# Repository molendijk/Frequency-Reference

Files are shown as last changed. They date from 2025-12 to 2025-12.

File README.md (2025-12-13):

  # 10MHz Frequency Reference Distributor and 25MHz generator and distributor.

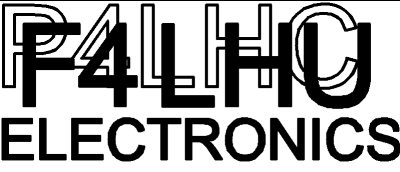
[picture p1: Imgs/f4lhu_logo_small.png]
F4LHU Logo
  
  
  ## Purpose
  
  This hardware project is intended for people posessing a 10MHz sinusoidal reference oscillator (GPS DO / Rubidium Source) 
  but require a 25MHz reference for use with an SDR (Adalm-Pluto), ADF4351 (Evaluation board) or a 
  LNB (modified Bulls-Eye).
  
  https://www.analog.com/en/resources/evaluation-hardware-and-software/evaluation-boards-kits/adalm-pluto.html
  https://github.com/molendijk/QO100_LO_ADF4351_Loader
  https://3b8mars.org/wp-content/uploads/2023/10/Bulleye-LNB-modification-for-external-clocking-updated-Oct2023.pdf

  ## Implementation

  The circuit first converts the incoming sine-wave to a square-wave. A potentiometer allows to set the square-wave
  duty factor to 50%. This square-wave is then presented to 3 external outputs of which 1 is DC coupled. A 4th internal
  copy is then available internally to be connected to the input of an external 50MHz band-pass filter.
  The 50MHz sinusoidal output of this filter is then connected to the 50MHz input, that is once again transformed to a 
  square-wave and finally divided by 2 to generate 25MHz that is presented to 4 outputs of which 2 are DC coupled.
  
  The circuit also has an interface J6 for the required power supplies (+15V, +5V) for the FE-5650 Rb frequency standard.
  As the FE-5650 module uses a 9 pin Cannon D connector, a special flat-cable with on one side the DB9 F and on the other
  side a 2 x 7 header is needed. The pin correspondances are marked in a table on page 2 of the schematic.
  Note that pin 1 of either connector are aligned (connected).
  
  ## Mounting sequence and Commissioning
  
  ### Preparations
  1. Solder SMD parts on F-side and B-side **EXCEPT: power jumpers R10, R14, R22 and Edge-mount coax connectors**
  2. Solder through-hole parts: potentiometer R15 and U6 regulator, LEDs D1 and D2 (Square pin is the cathode -> short leg).
  ### Power-supply
  3. Connect VBUS to a 16V power-supply and while measuring (with a DVM) the voltage between TP_GND and TP_15V
     trim potentiometer R15 to obtain 15V.
  4. Solder through-hole parts: potentiometers R12, R17 and regulators U2, U3.
  5. Trim potentiometer R17 while measuring TP_P5V to get 5V
  6. Trim potentiometer R12 while measuring TP_P3V3 to get 3.3V
  7. Solder power jumpers: R10, R14 (+5V and +3.3V) and measure the current going into VBUS (IBUS) to be ~30mA. 
  LED D2 should be lit.
  ### 10MHz distributor
  8. Solder Edge-mount SMA coax J1, J2, J3, J4, transistor Q1 and potentiometer R5.
  9. Inject 10MHz ~1.3Vpp in port 10MHz in (J4).
  9. With a DSO (Inputs high-Z) measure the signals at J1, J2 -> ~3.5Vpp AC and J3 -> ~3.5V DC (0 thru +3.5V)
  10. Trim R5 for 50% duty-factor (J1, J2 and J3) Note: V-bias at node C1, R6, R3 will be ~ +1.55V  
  ### 50MHz output
  11. Solder Edge-mount SMA coax J13, through-hole SMA coax: J5, J7, power jumper R22 (+15V, 50MHz gain stage), 
  transistor Q2 and potentiometer R23. 
  12. Connect a previously prepared BPF50 from port BPF50 in (J7) to BPF50 out (J5)
  13. With a DSO (Inputs high-Z) measure the signals on port MHz50 out (J13). -> 50MHz signal ~3.5Vpp AC
  14. Trim R23 for 50% duty-factor 
  ### 25MHz distributor
  15. Solder Edge-mount SMA coax : J9, J10, J11 and J12.
  16. With a DSO (Inputs high-Z) measure the signals on ports J9, J10: 25 MHz DC -> ~3.5V DC (0 thru +3.5V)
  17. With a DSO (Inputs high-Z) measure the signals on ports J11, J12: 25 MHz AC -> ~3.5V AC (50% duty-factor)
 
 Notes: 
  - At the level 17 test configuration IBUS ~0.2A at VBUS +16V
  - Regulator U3 will become hot (70°C) without any heatsink. This may be a good moment to add the heatsink.
  
  18. Connect a flat-cable to J6 and **before connecting the correct Rb reference (FE-5650)**, 
  measure the supply voltages on the DB9 connector.
  
| Pin | Function |
| --- | --- |
|  1  | +15V |
|  2  | Gnd +15V |
|  4  | +5V |
|  5  | Gnd +5V  |
	
  19. Power-down, connect the DB9 side of the flat-cable to the Rb reference, connect the Rb reference 10MHz output
  to J4 the 10MHz input.
  20. Power-up, check supplies, verify and if needed correct the 10MHz 50% duty-factor setting R5. 
  LED D1 should be lit once the Rb reference has reached operating temperature and is frequency locked.
  
  Notes: 
  - The FE-5650 will initially, while heating up, draw >1A from the 15V regulator.
  - The FE-5650 takes a few minutes to heat up and lock to the correct frequency.
  
  ## Trouble shooting
  - In case of no output on the 50MHz port, measure the DC voltages at the outputs of U4 (+3.4V) and U5 (+4.9V).
  If one of these is absent, verify the solder joints of either L1 or L2.
 
  ## Issues with Rev 1.0.0 built 20251031
  - The SMA Edge-mount connector footprints have a greater ground pin spacing than the "standard" Edge-mount SMA
  connectors available. Nevertheless these connectors can be soldered in place, bridging the slight gap between
  the pads and the connector Gnd pins.
  - The TO92 footprint of transistors Q1, Q2 (2N2222) has pin numbering 1,2,3 instead of 3,2,1 (collector emitter swap).
  The workaround is to mount Q1 and Q2 with the flat side opposite to that on the serigraphie.
  - C21 is too close to J6, the 2 x 7 pin header, effectively falling underneath the header plastic. By first mounting
  C21 and then letting the header stick out sufficiently the connector and capacitor can cohabitate.
  - As the 39 nF capacitors are not in the standard series these were replaced by 47 nF capacitors.

  ## Notes
  1. The series terminated DC Coupled outputs are intended to be connected to high-Z (3.3V) logic level inputs.
     The AC Coupled outputs can be terminated in 50 Ohms, typically like when connected to a clock input of an SDR.
  2. The 6th order 50MHz filter is constructed using 3 side-coupled (LC) resonating circuits that yield a good quality factor.
     More details on the construction of this filter will follow soon. 
  3. Certain devices need a sinusoidal 25MHz clock to operate correctly. In this case a simple low-pass filter can
     be used to remove much of the higher harmonics.
  4. Be sure to check permitted input signal levels on 25MHz inputs and if needed, add additional attenuation.

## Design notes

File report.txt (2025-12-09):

Info: Processing symbol 'C1:Capacitor_SMD:C_1206_3216Metric_Pad1.33x1.80mm_HandSolder'.
Info: Processing symbol 'R5:Resistor_SMD:R_1206_3216Metric_Pad1.30x1.75mm_HandSolder'.
Info: Processing symbol 'C21:Capacitor_SMD:C_1206_3216Metric_Pad1.33x1.80mm_HandSolder'.
Info: Processing symbol 'C2:Capacitor_SMD:C_1206_3216Metric_Pad1.33x1.80mm_HandSolder'.
Info: Processing symbol 'J13:Connector_Coaxial:SMA_Amphenol_132289_EdgeMount'.
Info: Processing symbol 'J2:Connector_Coaxial:SMA_Amphenol_132289_EdgeMount'.
Info: Processing symbol 'C3:Capacitor_SMD:C_1206_3216Metric_Pad1.33x1.80mm_HandSolder'.
Info: Processing symbol 'Q1:Package_TO_SOT_THT:TO-92_Inline'.
Info: Processing symbol 'C9:Capacitor_SMD:C_1206_3216Metric_Pad1.33x1.80mm_HandSolder'.
Info: Processing symbol 'C4:Capacitor_SMD:C_1206_3216Metric_Pad1.33x1.80mm_HandSolder'.
Info: Processing symbol 'C24:Capacitor_SMD:C_1206_3216Metric_Pad1.33x1.80mm_HandSolder'.
Info: Processing symbol 'R2:Resistor_SMD:R_2512_6332Metric_Pad1.40x3.35mm_HandSolder'.
Info: Processing symbol 'J3:Connector_Coaxial:SMA_Amphenol_132289_EdgeMount'.
Info: Processing symbol 'R7:Resistor_SMD:R_1206_3216Metric_Pad1.30x1.75mm_HandSolder'.
Info: Processing symbol 'C5:Capacitor_SMD:C_1206_3216Metric_Pad1.33x1.80mm_HandSolder'.
Info: Processing symbol 'C16:Capacitor_SMD:C_1206_3216Metric_Pad1.33x1.80mm_HandSolder'.
Info: Processing symbol 'C19:Capacitor_SMD:C_1206_3216Metric_Pad1.33x1.80mm_HandSolder'.
Info: Processing symbol 'C13:Capacitor_SMD:C_1206_3216Metric_Pad1.33x1.80mm_HandSolder'.
Info: Processing symbol 'C6:Capacitor_SMD:C_1206_3216Metric_Pad1.33x1.80mm_HandSolder'.
Info: Processing symbol 'L1:Library:Minicircuits_GU1604'.
Info: Processing symbol 'R6:Resistor_SMD:R_1206_3216Metric_Pad1.30x1.75mm_HandSolder'.
Info: Processing symbol 'J10:Connector_Coaxial:SMA_Amphenol_132289_EdgeMount'.
Info: Processing symbol 'C22:Capacitor_SMD:C_1206_3216Metric_Pad1.33x1.80mm_HandSolder'.
Info: Processing symbol 'C10:Capacitor_SMD:C_1206_3216Metric_Pad1.33x1.80mm_HandSolder'.
Info: Processing symbol 'J9:Connector_Coaxial:SMA_Amphenol_132289_EdgeMount'.
Info: Processing symbol 'R8:Resistor_SMD:R_1206_3216Metric_Pad1.30x1.75mm_HandSolder'.
Info: Processing symbol 'J8:Connector_PinHeader_2.54mm:PinHeader_2x07_P2.54mm_Vertical'.
Info: Processing symbol 'J6:Connector_Coaxial:SMA_Amphenol_132289_EdgeMount'.
Info: Processing symbol 'C25:Capacitor_SMD:C_1206_3216Metric_Pad1.33x1.80mm_HandSolder'.
Info: Processing symbol 'J11:Connector_Coaxial:SMA_Amphenol_132289_EdgeMount'.
Info: Processing symbol 'C17:Capacitor_SMD:C_1206_3216Metric_Pad1.33x1.80mm_HandSolder'.
Info: Processing symbol 'C7:Capacitor_SMD:C_1206_3216Metric_Pad1.33x1.80mm_HandSolder'.
Info: Processing symbol 'C14:Capacitor_SMD:C_1206_3216Metric_Pad1.33x1.80mm_HandSolder'.
Info: Processing symbol 'R3:Resistor_SMD:R_1206_3216Metric_Pad1.30x1.75mm_HandSolder'.
Info: Processing symbol 'C20:Capacitor_SMD:C_1206_3216Metric_Pad1.33x1.80mm_HandSolder'.
Info: Processing symbol 'J7:Connector_Coaxial:SMA_Amphenol_132289_EdgeMount'.
Info: Processing symbol 'C11:Capacitor_SMD:C_1206_3216Metric_Pad1.33x1.80mm_HandSolder'.
Info: Processing symbol 'R1:Resistor_SMD:R_2512_6332Metric_Pad1.40x3.35mm_HandSolder'.
Info: Processing symbol 'J12:Connector_Coaxial:SMA_Amphenol_132289_EdgeMount'.
Info: Processing symbol 'C23:Capacitor_SMD:C_1206_3216Metric_Pad1.33x1.80mm_HandSolder'.
Info: Processing symbol 'L2:Library:Minicircuits_GU1604'.
Info: Processing symbol 'J4:Connector_Coaxial:SMA_Amphenol_132289_EdgeMount'.
Info: Processing symbol 'R4:Resistor_SMD:R_1206_3216Metric_Pad1.30x1.75mm_HandSolder'.
Info: Processing symbol 'C8:Capacitor_SMD:C_1206_3216Metric_Pad1.33x1.80mm_HandSolder'.
Info: Processing symbol 'Q2:Package_TO_SOT_THT:TO-92_Inline'.
Info: Processing symbol 'C18:Capacitor_SMD:C_1206_3216Metric_Pad1.33x1.80mm_HandSolder'.
Info: Processing symbol 'C15:Capacitor_SMD:C_1206_3216Metric_Pad1.33x1.80mm_HandSolder'.
Info: Processing symbol 'J5:Connector_BarrelJack:BarrelJack_Horizontal'.
Info: Processing symbol 'J1:Connector_Coaxial:SMA_Amphenol_132289_EdgeMount'.
Info: Processing symbol 'C12:Capacitor_SMD:C_1206_3216Metric_Pad1.33x1.80mm_HandSolder'.
Info: Processing symbol 'R9:Resistor_SMD:R_1206_3216Metric_Pad1.30x1.75mm_HandSolder'.
Info: Processing symbol 'R10:Resistor_SMD:R_1206_3216Metric_Pad1.30x1.75mm_HandSolder'.
Info: Processing symbol 'R11:Potentiometer_THT:Potentiometer_Bourns_3299W_Vertical'.
Info: Processing symbol 'R12:Resistor_SMD:R_1206_3216Metric_Pad1.30x1.75mm_HandSolder'.
Info: Processing symbol 'R13:Potentiometer_THT:Potentiometer_Bourns_3299W_Vertical'.
Info: Processing symbol 'R14:Resistor_SMD:R_1206_3216Metric_Pad1.30x1.75mm_HandSolder'.
Info: Processing symbol 'R15:Potentiometer_THT:Potentiometer_Bourns_3299W_Vertical'.
Info: Processing symbol 'R16:Resistor_SMD:R_1206_3216Metric_Pad1.30x1.75mm_HandSolder'.
Info: Processing symbol 'R17:Resistor_SMD:R_1206_3216Metric_Pad1.30x1.75mm_HandSolder'.
Info: Processing symbol 'R18:Resistor_SMD:R_1206_3216Metric_Pad1.30x1.75mm_HandSolder'.
Info: Processing symbol 'R19:Resistor_SMD:R_1206_3216Metric_Pad1.30x1.75mm_HandSolder'.
Info: Processing symbol 'R20:Resistor_SMD:R_1206_3216Metric_Pad1.30x1.75mm_HandSolder'.
Info: Processing symbol 'R21:Potentiometer_THT:Potentiometer_Bourns_3299W_Vertical'.
Info: Processing symbol 'R22:Resistor_SMD:R_1206_3216Metric_Pad1.30x1.75mm_HandSolder'.
Info: Processing symbol 'R23:Resistor_SMD:R_1206_3216Metric_Pad1.30x1.75mm_HandSolder'.
Info: Processing symbol 'R24:Resistor_SMD:R_1206_3216Metric_Pad1.30x1.75mm_HandSolder'.
Info: Processing symbol 'R25:Resistor_SMD:R_1206_3216Metric_Pad1.30x1.75mm_HandSolder'.
Info: Processing symbol 'R26:Resistor_SMD:R_1206_3216Metric_Pad1.30x1.75mm_HandSolder'.
Info: Processing symbol 'R27:Resistor_SMD:R_1206_3216Metric_Pad1.30x1.75mm_HandSolder'.
Info: Total warnings: 9, errors: 0.
Info: Processing symbol 'R28:Resistor_SMD:R_1206_3216Metric_Pad1.30x1.75mm_HandSolder'.
Info: Processing symbol 'R29:Potentiometer_THT:Potentiometer_Bourns_3299W_Vertical'.
Info: Processing symbol 'R30:Resistor_SMD:R_1206_3216Metric_Pad1.30x1.75mm_HandSolder'.
Info: Processing symbol 'R31:Resistor_SMD:R_1206_3216Metric_Pad1.30x1.75mm_HandSolder'.
Info: Processing symbol 'R32:Resistor_SMD:R_1206_3216Metric_Pad1.30x1.75mm_HandSolder'.
Info: Processing symbol 'TP1:TestPoint:TestPoint_Plated_Hole_D2.0mm'.
Info: Processing symbol 'TP2:TestPoint:TestPoint_Plated_Hole_D2.0mm'.
Info: Processing symbol 'TP3:TestPoint:TestPoint_Plated_Hole_D2.0mm'.
Info: Processing symbol 'TP4:TestPoint:TestPoint_Plated_Hole_D2.0mm'.
Info: Processing symbol 'TP5:TestPoint:TestPoint_Plated_Hole_D2.0mm'.
Info: Processing symbol 'TP6:TestPoint:TestPoint_Plated_Hole_D2.0mm'.
Info: Processing symbol 'TP7:TestPoint:TestPoint_Plated_Hole_D2.0mm'.
Info: Processing symbol 'TP8:TestPoint:TestPoint_Plated_Hole_D2.0mm'.
Info: Processing symbol 'U1:Library:WW107'.
Info: Processing symbol 'U2:Library:WW107'.
Info: Processing symbol 'U3:Package_SO:SSOP-8_2.95x2.8mm_P0.65mm'.
Info: Processing symbol 'U4:Package_TO_SOT_SMD:TO-263-3_TabPin2'.
Info: Processing symbol 'U5:Package_SO:SOIC-8_5.3x6.2mm_P1.27mm'.
Info: Processing symbol 'U6:Package_SO:SOIC-8_5.3x6.2mm_P1.27mm'.
Info: Processing symbol 'U7:Package_TO_SOT_SMD:TO-263-3_TabPin2'.
Info: Processing symbol 'U8:Package_TO_SOT_SMD:TO-263-3_TabPin2'.
Info: Processing symbol 'U9:Package_SO:SOIC-8_5.3x6.2mm_P1.27mm'.
Updated C8 sheetfile to 'ClockDistri.kicad_sch'.
Updated C8 footprint filters to 'CP_*'.
Connected C8 pin 2 to GND.
Add net VBUS.
Connected C8 pin 1 to VBUS.
Added C9 (footprint 'Capacitor_SMD:C_1206_3216Metric_Pad1.33x1.80mm_HandSolder').
Changed REF** reference designator to C9.
Changed C9 value from C_1206_3216Metric_Pad1.33x1.80mm_HandSolder to 47uF.
Updated C9 symbol association from  to /19e25b7f-f11f-43c6-9ca8-c0c99fb9a488/27e5c7c0-e4c8-4e1d-91d9-dbcf634c3cf4.
Updated C9 fields.
Updated C9 sheetname to '/PowerSupplies/'.
Updated C9 sheetfile to 'ClockDistri.kicad_sch'.
Updated C9 footprint filters to 'CP_*'.
Connected C9 pin 2 to GND.
Add net Net-(J8-Pin_1).
Connected C9 pin 1 to Net-(J8-Pin_1).
Added C10 (footprint 'Capacitor_SMD:C_1206_3216Metric_Pad1.33x1.80mm_HandSolder').
Changed REF** reference designator to C10.
Changed C10 value from C_1206_3216Metric_Pad1.33x1.80mm_HandSolder to 47uF.
Updated C10 symbol association from  to /19e25b7f-f11f-43c6-9ca8-c0c99fb9a488/b20e4947-729c-45ab-a11c-5afa4ca6e5d3.
Updated C10 fields.
Updated C10 sheetname to '/PowerSupplies/'.
Updated C10 sheetfile to 'ClockDistri.kicad_sch'.
Updated C10 footprint filters to 'CP_*'.
Add net Net-(J8-Pin_7).
Connected C10 pin 1 to Net-(J8-Pin_7).
Connected C10 pin 2 to GND.
Added C11 (footprint 'Capacitor_SMD:C_1206_3216Metric_Pad1.33x1.80mm_HandSolder').
Changed REF** reference designator to C11.
Changed C11 value from C_1206_3216Metric_Pad1.33x1.80mm_HandSolder to 47uF.
Updated C11 symbol association from  to /19e25b7f-f11f-43c6-9ca8-c0c99fb9a488/a415be0a-ee04-4ad4-88dc-ad9cb893901c.
Updated C11 fields.
Updated C11 sheetname to '/PowerSupplies/'.
Updated C11 sheetfile to 'ClockDistri.kicad_sch'.
Updated C11 footprint filters to 'CP_*'.
Add net Net-(U8-VO).
Connected C11 pin 1 to Net-(U8-VO).
Connected C11 pin 2 to GND.
Added C12 (footprint 'Capacitor_SMD:C_1206_3216Metric_Pad1.33x1.80mm_HandSolder').
Changed REF** reference designator to C12.
Changed C12 value from C_1206_3216Metric_Pad1.33x1.80mm_HandSolder to 22uF.
Updated C12 symbol association from  to /19e25b7f-f11f-43c6-9ca8-c0c99fb9a488/99ee4937-7fed-4c68-beed-ca436922dd44.
Updated C12 fields.
Updated C12 sheetname to '/PowerSupplies/'.
Updated C12 sheetfile to 'ClockDistri.kicad_sch'.
Updated C12 footprint filters to 'CP_*'.
Add net Net-(U7-ADJ).
Connected C12 pin 1 to Net-(U7-ADJ).
Connected C12 pin 2 to GND.
Added C13 (footprint 'Capacitor_SMD:C_1206_3216Metric_Pad1.33x1.80mm_HandSolder').
Changed REF** reference designator to C13.
Changed C13 value from C_1206_3216Metric_Pad1.33x1.80mm_HandSolder to 22uF.
Updated C13 symbol association from  to /19e25b7f-f11f-43c6-9ca8-c0c99fb9a488/53d6d50d-ee43-436f-992a-71831d127ff6.
Updated C13 fields.
Updated C13 sheetname to '/PowerSupplies/'.
Updated C13 sheetfile to 'ClockDistri.kicad_sch'.
Updated C13 footprint filters to 'CP_*'.
Add net Net-(U8-ADJ).
Connected C13 pin 1 to Net-(U8-ADJ).
Connected C13 pin 2 to GND.
Added C14 (footprint 'Capacitor_SMD:C_1206_3216Metric_Pad1.33x1.80mm_HandSolder').
Changed REF** reference designator to C14.
Changed C14 value from C_1206_3216Metric_Pad1.33x1.80mm_HandSolder to 22uF.
Updated C14 symbol association from  to /19e25b7f-f11f-43c6-9ca8-c0c99fb9a488/779a9825-380a-40c6-be76-97d7fdc0159a.
Updated C14 fields.
Updated C14 sheetname to '/PowerSupplies/'.
Updated C14 sheetfile to 'ClockDistri.kicad_sch'.
Updated C14 footprint filters to 'CP_*'.
Connected C14 pin 2 to GND.
Add net Net-(U4-ADJ).
Connected C14 pin 1 to Net-(U4-ADJ).
Added C15 (footprint 'Capacitor_SMD:C_1206_3216Metric_Pad1.33x1.80mm_HandSolder').
Changed REF** reference designator to C15.
Changed C15 value from C_1206_3216Metric_Pad1.33x1.80mm_HandSolder to 100nF.
Updated C15 symbol association from  to /587d7fd0-7b34-44bf-a0ec-ae7bf4ed02c7.
Updated C15 fields.
Updated C15 sheetname to '/'.
Updated C15 sheetfile to 'Freq_Reference.kicad_sch'.
Updated C15 footprint filters to 'C_*'.
Connected C15 pin 1 to GND.
Add net Net-(Q2-B).
Connected C15 pin 2 to Net-(Q2-B).
Added C16 (footprint 'Capacitor_SMD:C_1206_3216Metric_Pad1.33x1.80mm_HandSolder').
Changed REF** reference designator to C16.
Changed C16 value from C_1206_3216Metric_Pad1.33x1.80mm_HandSolder to 39nF.
Updated C16 symbol association from  to /6c447208-1996-437b-8c30-de446bbd3cab.
Updated C16 fields.
Updated C16 sheetname to '/'.
Updated C16 sheetfile to 'Freq_Reference.kicad_sch'.
Updated C16 footprint filters to 'C_*'.
Add net Net-(C16-Pad1).
Connected C16 pin 1 to Net-(C16-Pad1).
Connected C16 pin 2 to GND.
Added C17 (footprint 'Capacitor_SMD:C_1206_3216Metric_Pad1.33x1.80mm_HandSolder').
Changed REF** reference designator to C17.
Changed C17 value from C_1206_3216Metric_Pad1.33x1.80mm_HandSolder to 1uF.
Updated C17 symbol association from  to /ebffa0a9-fa4d-4ada-a95c-21fc8a085352.
Updated C17 fields.
Updated C17 sheetname to '/'.
Updated C17 sheetfile to 'Freq_Reference.kicad_sch'.
Updated C17 footprint filters to 'C_*'.
Connected C17 pin 2 to Net-(C16-Pad1).
Connected C17 pin 1 to GND.
Added C18 (footprint 'Capacitor_SMD:C_1206_3216Metric_Pad1.33x1.80mm_HandSolder').
Changed REF** reference designator to C18.
Changed C18 value from C_1206_3216Metric_Pad1.33x1.80mm_HandSolder to 39nF.
Updated C18 symbol association from  to /673c9a1c-68e8-4ecc-9c92-ebbabf77a1cd.
Updated C18 fields.
Updated C18 sheetname to '/'.
Updated C18 sheetfile to 'Freq_Reference.kicad_sch'.
Updated C18 footprint filters to 'C_*'.
Connected C18 pin 2 to GND.
Add net Net-(Q1-E).
Connected C18 pin 1 to Net-(Q1-E).
Added C19 (footprint 'Capacitor_SMD:C_1206_3216Metric_Pad1.33x1.80mm_HandSolder').
Changed REF** reference designator to C19.
Changed C19 value from C_1206_3216Metric_Pad1.33x1.80mm_HandSolder to 39nF.
Updated C19 symbol association from  to /a4f53673-f229-4935-9d42-51c9ade87ad7.
Updated C19 fields.
Updated C19 sheetname to '/'.
Updated C19 sheetfile to 'Freq_Reference.kicad_sch'.
Updated C19 footprint filters to 'C_*'.
Connected C19 pin 2 to GND.
Add net Net-(Q2-E).
Connected C19 pin 1 to Net-(Q2-E).
Added C20 (footprint 'Capacitor_SMD:C_1206_3216Metric_Pad1.33x1.80mm_HandSolder').
Changed REF** reference designator to C20.
Changed C20 value from C_1206_3216Metric_Pad1.33x1.80mm_HandSolder to 1uF.
Updated C20 symbol association from  to /c03fc493-f095-4c8b-b1b0-a7ec03b12a23.
Updated C20 fields.
Updated C20 sheetname to '/'.
Updated C20 sheetfile to 'Freq_Reference.kicad_sch'.
Updated C20 footprint filters to 'C_*'.
Add net Net-(C20-Pad2).
Connected C20 pin 2 to Net-(C20-Pad2).
Connected C20 pin 1 to GND.
Added C21 (footprint 'Capacitor_SMD:C_1206_3216Metric_Pad1.33x1.80mm_HandSolder').
Changed REF** reference designator to C21.
Changed C21 value from C_1206_3216Metric_Pad1.33x1.80mm_HandSolder to 39nF.
Updated C21 symbol association from  to /69341308-b7ec-468b-90af-18e7545a2889.
Updated C21 fields.
Updated C21 sheetname to '/'.
Updated C21 sheetfile to 'Freq_Reference.kicad_sch'.
Updated C21 footprint filters to 'C_*'.
Connected C21 pin 2 to GND.
Connected C21 pin 1 to Net-(C20-Pad2).
Added C22 (footprint 'Capacitor_SMD:C_1206_3216Metric_Pad1.33x1.80mm_HandSolder').
Changed REF** reference designator to C22.
Changed C22 value from C_1206_3216Metric_Pad1.33x1.80mm_HandSolder to 39nF.
Updated C22 symbol association from  to /09e92692-0717-472e-b4b6-a50c8216932f.
Updated C22 fields.
Updated C22 sheetname to '/'.
Updated C22 sheetfile to 'Freq_Reference.kicad_sch'.
Updated C22 footprint filters to 'C_*'.
Connected C22 pin 1 to +3.3V.
Connected C22 pin 2 to GND.
Added C23 (footprint 'Capacitor_SMD:C_1206_3216Metric_Pad1.33x1.80mm_HandSolder').
Changed REF** reference designator to C23.
Changed C23 value from C_1206_3216Metric_Pad1.33x1.80mm_HandSolder to 39nF.
Updated C23 symbol association from  to /9c059ba8-eb20-4027-9856-53d2b9bf8cac.
Updated C23 fields.
Updated C23 sheetname to '/'.
Updated C23 sheetfile to 'Freq_Reference.kicad_sch'.
Updated C23 footprint filters to 'C_*'.
Connected C23 pin 2 to GND.
Connected C23 pin 1 to +3.3V.
Added C24 (footprint 'Capacitor_SMD:C_1206_3216Metric_Pad1.33x1.80mm_HandSolder').
Changed REF** reference designator to C24.
Changed C24 value from C_1206_3216Metric_Pad1.33x1.80mm_HandSolder to 39nF.
Updated C24 symbol association from  to /670d0a66-c874-48b3-ac8c-e8d85d931bfe.
Updated C24 fields.
Updated C24 sheetname to '/'.
Updated C24 sheetfile to 'Freq_Reference.kicad_sch'.
Updated C24 footprint filters to 'C_*'.
Connected C24 pin 2 to GND.
Connected C24 pin 1 to +3.3V.
Added C25 (footprint 'Capacitor_SMD:C_1206_3216Metric_Pad1.33x1.80mm_HandSolder').
Changed REF** reference designator to C25.
Changed C25 value from C_1206_3216Metric_Pad1.33x1.80mm_HandSolder to 39nF.
Updated C25 symbol association from  to /faf82ec7-362b-495d-863f-135f0d69d378.
Updated C25 fields.
Updated C25 sheetname to '/'.
Updated C25 sheetfile to 'Freq_Reference.kicad_sch'.
Updated C25 footprint filters to 'C_*'.
Connected C25 pin 1 to +3.3V.
Connected C25 pin 2 to GND.
Updated J1 fields.
Updated J1 sheetfile to 'Freq_Reference.kicad_sch'.
Updated J2 fields.
Updated J2 sheetfile to 'Freq_Reference.kicad_sch'.
Added J3 (footprint 'Connector_Coaxial:SMA_Amphenol_132289_EdgeMount').
Changed REF** reference designator to J3.
Changed J3 value from SMA_Amphenol_132289_EdgeMount to Conn_Coaxial_Small.
Updated J3 symbol association from  to /53538eb5-029b-4884-8540-a9824974924f.
Updated J3 fields.
Updated J3 sheetname to '/'.
Updated J3 sheetfile to 'Freq_Reference.kicad_sch'.
Updated J3 footprint filters to '*BNC* *SMA* *SMB* *SMC* *Cinch* *LEMO* *UMRF* *MCX* *U.FL*'.
Connected J3 pin 2 to GND.
Add net Net-(J3-In).
Connected J3 pin 1 to Net-(J3-In).
Connected J3 pin 2 to GND.
Connected J3 pin 2 to GND.
Connected J3 pin 2 to GND.
Updated J4 fields.
Updated J4 sheetfile to 'Freq_Reference.kicad_sch'.
Added J5 (footprint 'Connector_BarrelJack:BarrelJack_Horizontal').
Changed REF** reference designator to J5.
Changed J5 value from BarrelJack_Horizontal to Jack-DC.
Updated J5 symbol association from  to /19e25b7f-f11f-43c6-9ca8-c0c99fb9a488/a68c2d15-3dc7-422a-a2dd-c7c9dbd4d9a6.
Updated J5 fields.
Updated J5 sheetname to '/PowerSupplies/'.
Updated J5 sheetfile to 'ClockDistri.kicad_sch'.
Updated J5 footprint filters to 'BarrelJack*'.
Connected J5 pin 2 to GND.
Connected J5 pin 1 to VBUS.
Updated J6 fields.
Updated J6 sheetfile to 'Freq_Reference.kicad_sch'.
Added J7 (footprint 'Connector_Coaxial:SMA_Amphenol_132289_EdgeMount').
Changed REF** reference designator to J7.
Changed J7 value from SMA_Amphenol_132289_EdgeMount to Conn_Coaxial_Small.
Updated J7 symbol association from  to /ade44c3a-5c98-4127-9fd3-751c3f6859d4.
Updated J7 fields.
Updated J7 sheetname to '/'.
Updated J7 sheetfile to 'Freq_Reference.kicad_sch'.
Updated J7 footprint filters to '*BNC* *SMA* *SMB* *SMC* *Cinch* *LEMO* *UMRF* *MCX* *U.FL*'.
Connected J7 pin 2 to GND.
Connected J7 pin 2 to GND.
Connected J7 pin 2 to GND.
Add net Net-(J7-In).
Connected J7 pin 1 to Net-(J7-In).
Connected J7 pin 2 to GND.
Added J8 (footprint 'Connector_PinHeader_2.54mm:PinHeader_2x07_P2.54mm_Vertical').
Changed REF** reference designator to J8.
Changed J8 value from PinHeader_2x07_P2.54mm_Vertical to Conn_02x07_Odd_Even.
Updated J8 symbol association from  to /19e25b7f-f11f-43c6-9ca8-c0c99fb9a488/282b8dfc-f45e-47d8-ac74-86026d99b6d7.
Updated J8 fields.
Updated J8 sheetname to '/PowerSupplies/'.
Updated J8 sheetfile to 'ClockDistri.kicad_sch'.
Updated J8 footprint filters to 'Connector*:*_2x??_*'.
Connected J8 pin 1 to Net-(J8-Pin_1).
Add net unconnected-(J8-Pin_10-Pad10).
Connected J8 pin 10 to unconnected-(J8-Pin_10-Pad10).
Add net unconnected-(J8-Pin_8-Pad8).
Connected J8 pin 8 to unconnected-(J8-Pin_8-Pad8).
Connected J8 pin 9 to GND.
Add net unconnected-(J8-Pin_12-Pad12).
Connected J8 pin 12 to unconnected-(J8-Pin_12-Pad12).
Add net unconnected-(J8-Pin_5-Pad5).
Connected J8 pin 5 to unconnected-(J8-Pin_5-Pad5).
Add net unconnected-(J8-Pin_13-Pad13).
Connected J8 pin 13 to unconnected-(J8-Pin_13-Pad13).
Add net unconnected-(J8-Pin_4-Pad4).
Connected J8 pin 4 to unconnected-(J8-Pin_4-Pad4).
Add net unconnected-(J8-Pin_14-Pad14).
Connected J8 pin 14 to unconnected-(J8-Pin_14-Pad14).
Connected J8 pin 2 to GND.
Add net unconnected-(J8-Pin_6-Pad6).
Connected J8 pin 6 to unconnected-(J8-Pin_6-Pad6).
Add net unconnected-(J8-Pin_11-Pad11).
Connected J8 pin 11 to unconnected-(J8-Pin_11-Pad11).
Connected J8 pin 3 to GND.
Connected J8 pin 7 to Net-(J8-Pin_7).
Added J9 (footprint 'Connector_Coaxial:SMA_Amphenol_132289_EdgeMount').
Changed REF** reference designator to J9.
Changed J9 value from SMA_Amphenol_132289_EdgeMount to Conn_Coaxial_Small.
Updated J9 symbol association from  to /3e9de054-da3d-4130-ae46-7479a23cc6ca.
Updated J9 fields.
Updated J9 sheetname to '/'.
Updated J9 sheetfile to 'Freq_Reference.kicad_sch'.
Updated J9 footprint filters to '*BNC* *SMA* *SMB* *SMC* *Cinch* *LEMO* *UMRF* *MCX* *U.FL*'.
Connected J9 pin 2 to GND.
Connected J9 pin 2 to GND.
Add net Net-(J9-In).
Connected J9 pin 1 to Net-(J9-In).
Connected J9 pin 2 to GND.
Connected J9 pin 2 to GND.
Added J10 (footprint 'Connector_Coaxial:SMA_Amphenol_132289_EdgeMount').
Changed REF** reference designator to J10.
Changed J10 value from SMA_Amphenol_132289_EdgeMount to Conn_Coaxial_Small.
Updated J10 symbol association from  to /dda4fd4b-18b2-482b-b9c9-32f06f5ca0d1.
Updated J10 fields.
Updated J10 sheetfile to 'Freq_Reference.kicad_sch'.
Updated J10 footprint filters to '*BNC* *SMA* *SMB* *SMC* *Cinch* *LEMO* *UMRF* *MCX* *U.FL*'.
Connected J10 pin 2 to GND.
Connected J10 pin 2 to GND.
Connected J10 pin 2 to GND.
Connected J10 pin 2 to GND.
Add net Net-(J10-In).
Connected J10 pin 1 to Net-(J10-In).
Added J11 (footprint 'Connector_Coaxial:SMA_Amphenol_132289_EdgeMount').
Changed REF** reference designator to J11.
Changed J11 value from SMA_Amphenol_132289_EdgeMount to Conn_Coaxial_Small.
Updated J11 symbol association from  to /da186231-41d8-448f-a09b-173a8f8d9fc9.
Updated J11 fields.
Updated J11 sheetname to '/'.
Updated J11 sheetfile to 'Freq_Reference.kicad_sch'.
Updated J11 footprint filters to '*BNC* *SMA* *SMB* *SMC* *Cinch* *LEMO* *UMRF* *MCX* *U.FL*'.
Connected J11 pin 2 to GND.
Connected J11 pin 2 to GND.
Add net Net-(J11-In).
Connected J11 pin 1 to Net-(J11-In).
Connected J11 pin 2 to GND.
Connected J11 pin 2 to GND.
Added J12 (footprint 'Connector_Coaxial:SMA_Amphenol_132289_EdgeMount').
Changed REF** reference designator to J12.
Changed J12 value from SMA_Amphenol_132289_EdgeMount to Conn_Coaxial_Small.
Updated J12 symbol association from  to /d6aadbf4-0e74-419b-bbd0-b599f2c85937.
Updated J12 fields.
Updated J12 sheetname to '/'.
Updated J12 sheetfile to 'Freq_Reference.kicad_sch'.
Updated J12 footprint filters to '*BNC* *SMA* *SMB* *SMC* *Cinch* *LEMO* *UMRF* *MCX* *U.FL*'.
Connected J12 pin 2 to GND.
Connected J12 pin 2 to GND.
Connected J12 pin 2 to GND.
Connected J12 pin 2 to GND.
Add net Net-(J12-In).
Connected J12 pin 1 to Net-(J12-In).
Added J13 (footprint 'Connector_Coaxial:SMA_Amphenol_132289_EdgeMount').
Changed REF** reference designator to J13.
Changed J13 value from SMA_Amphenol_132289_EdgeMount to Conn_Coaxial_Small.
Updated J13 symbol association from  to /c807c0ab-1d16-45ae-8be6-4f6555b1990c.
Updated J13 fields.
Updated J13 sheetname to '/'.
Updated J13 sheetfile to 'Freq_Reference.kicad_sch'.
Updated J13 footprint filters to '*BNC* *SMA* *SMB* *SMC* *Cinch* *LEMO* *UMRF* *MCX* *U.FL*'.
Connected J13 pin 2 to GND.
Connected J13 pin 2 to GND.
Connected J13 pin 2 to GND.
Connected J13 pin 1 to Net-(J13-In).
Connected J13 pin 2 to GND.
Added L1 (footprint 'Library:Minicircuits_GU1604').
Changed L** reference designator to L1.
Changed L1 value from GU1604 to TCCH-80+.
Updated L1 symbol association from  to /0653adb7-e871-48e0-ab44-da0109c4a5e6.
Updated L1 fields.
Updated L1 sheetname to '/'.
Updated L1 sheetfile to 'Freq_Reference.kicad_sch'.
Updated L1 footprint filters to 'Choke_* *Coil* Inductor_* L_*'.
Connected L1 pin 1 to Net-(C2-Pad1).
Connected L1 pin 3 to Net-(C16-Pad1).
Changed L2 footprint from 'Inductor_THT:L_Axial_L14.0mm_D4.5mm_P15.24mm_Horizontal_Fastron_LACC' to 'Library:Minicircuits_GU1604'.
Changed L2 value from 10uH to TCCH-80+.
Updated L2 fields.
Updated L2 sheetfile to 'Freq_Reference.kicad_sch'.
Connected L2 pin 3 to Net-(C20-Pad2).
Disconnected L2 pin 2.
Reconnected L2 pin 1 from Net-(L2-Pad1) to Net-(C3-Pad1).
Added Q1 (footprint 'Package_TO_SOT_THT:TO-92_Inline').
Changed REF** reference designator to Q1.
Changed Q1 value from TO-92_Inline to 2N2222.
Updated Q1 symbol association from  to /87cd8ec4-d0ee-4e28-a457-ae871a82ea1e.
Updated Q1 fields.
Updated Q1 sheetname to '/'.
Updated Q1 sheetfile to 'Freq_Reference.kicad_sch'.
Updated Q1 footprint filters to 'TO?92*'.
Connected Q1 pin 2 to Net-(Q1-B).
Connected Q1 pin 1 to Net-(Q1-E).
Connected Q1 pin 3 to +5V.
Added Q2 (footprint 'Package_TO_SOT_THT:TO-92_Inline').
Changed REF** reference designator to Q2.
Changed Q2 value from TO-92_Inline to 2N2222.
Updated Q2 symbol association from  to /b7d8b4d7-46a5-48fc-8264-01012edfd1ce.
Updated Q2 fields.
Updated Q2 sheetname to '/'.
Updated Q2 sheetfile to 'Freq_Reference.kicad_sch'.
Updated Q2 footprint filters to 'TO?92*'.
Connected Q2 pin 1 to Net-(Q2-E).
Connected Q2 pin 2 to Net-(Q2-B).
Connected Q2 pin 3 to +5V.
Changed R1 footprint from 'Resistor_THT:R_Axial_DIN0207_L6.3mm_D2.5mm_P10.16mm_Horizontal' to 'Resistor_SMD:R_2512_6332Metric_Pad1.40x3.35mm_HandSolder'.
Changed R1 value from 115 to 300.
Updated R1 fields.
Updated R1 sheetfile to 'Freq_Reference.kicad_sch'.
Reconnected R1 pin 2 from Net-(L1-Pad1) to Net-(C16-Pad1).
Reconnected R1 pin 1 from +9V to +15V.
Changed R2 footprint from 'Resistor_THT:R_Axial_DIN0207_L6.3mm_D2.5mm_P10.16mm_Horizontal' to 'Resistor_SMD:R_2512_6332Metric_Pad1.40x3.35mm_HandSolder'.
Changed R2 value from 75 to 160.
Updated R2 fields.
Updated R2 sheetfile to 'Freq_Reference.kicad_sch'.
Reconnected R2 pin 1 from +9V to +15V.
Reconnected R2 pin 2 from Net-(L2-Pad1) to Net-(C20-Pad2).
Changed R3 footprint from 'Resistor_THT:R_Axial_DIN0207_L6.3mm_D2.5mm_P10.16mm_Horizontal' to 'Resistor_SMD:R_1206_3216Metric_Pad1.30x1.75mm_HandSolder'.
Changed R3 value from 2k4 to 100.
Updated R3 fields.
Updated R3 sheetfile to 'Freq_Reference.kicad_sch'.
Reconnected R3 pin 1 from +5V to Net-(Q1-E).
Updated J10 sheetname to '/'.
Changed R4 footprint from 'Resistor_THT:R_Axial_DIN0207_L6.3mm_D2.5mm_P10.16mm_Horizontal' to 'Resistor_SMD:R_1206_3216Metric_Pad1.30x1.75mm_HandSolder'.
Changed R4 value from 2k4 to 100.
Updated R4 fields.
Updated R4 sheetfile to 'Freq_Reference.kicad_sch'.
Changed R5 footprint from 'Resistor_THT:R_Axial_DIN0207_L6.3mm_D2.5mm_P10.16mm_Horizontal' to 'Resistor_SMD:R_1206_3216Metric_Pad1.30x1.75mm_HandSolder'.
Updated R5 fields.
Updated R5 sheetfile to 'Freq_Reference.kicad_sch'.
Changed R6 footprint from 'Resistor_THT:R_Axial_DIN0207_L6.3mm_D2.5mm_P10.16mm_Horizontal' to 'Resistor_SMD:R_1206_3216Metric_Pad1.30x1.75mm_HandSolder'.
Updated R6 fields.
Updated R6 sheetfile to 'Freq_Reference.kicad_sch'.
Add net Net-(R6-Pad2).
Reconnected R6 pin 2 from Net-(J4-In) to Net-(R6-Pad2).
Changed R7 footprint from 'Resistor_THT:R_Axial_DIN0207_L6.3mm_D2.5mm_P10.16mm_Horizontal' to 'Resistor_SMD:R_1206_3216Metric_Pad1.30x1.75mm_HandSolder'.
Updated R7 fields.
Updated R7 sheetfile to 'Freq_Reference.kicad_sch'.
Add net Net-(R7-Pad2).
Reconnected R7 pin 2 from Net-(J5-In) to Net-(R7-Pad2).
Changed R8 footprint from 'Resistor_THT:R_Axial_DIN0207_L6.3mm_D2.5mm_P10.16mm_Horizontal' to 'Resistor_SMD:R_1206_3216Metric_Pad1.30x1.75mm_HandSolder'.
Updated R8 fields.
Updated R8 sheetfile to 'Freq_Reference.kicad_sch'.
Updated C1 fields.
Added R9 (footprint 'Resistor_SMD:R_1206_3216Metric_Pad1.30x1.75mm_HandSolder').
Changed REF** reference designator to R9.
Changed R9 value from R_1206_3216Metric_Pad1.30x1.75mm_HandSolder to 30.
Updated R9 symbol association from  to /7ab2e9fd-73cf-4cd2-8eda-0393b2ae8886.
Updated R9 fields.
Updated R9 sheetname to '/'.
Updated R9 sheetfile to 'Freq_Reference.kicad_sch'.
Updated R9 footprint filters to 'R_*'.
Add net Net-(U9-Q1).
Connected R9 pin 1 to Net-(U9-Q1).
Connected R9 pin 2 to Net-(J2-In).
Updated C1 sheetfile to 'Freq_Reference.kicad_sch'.
Added R10 (footprint 'Resistor_SMD:R_1206_3216Metric_Pad1.30x1.75mm_HandSolder').
Changed REF** reference designator to R10.
Changed R10 value from R_1206_3216Metric_Pad1.30x1.75mm_HandSolder to 5k1.
Updated R10 symbol association from  to /866e322a-f16c-4a6c-b9a3-aad0bac8bd52.
Updated R10 fields.
Updated R10 sheetname to '/'.
Updated R10 sheetfile to 'Freq_Reference.kicad_sch'.
Updated R10 footprint filters to 'R_*'.
Connected R10 pin 1 to Net-(Q1-B).
Connected R10 pin 2 to GND.
Updated C2 fields.
Added R11 (footprint 'Potentiometer_THT:Potentiometer_Bourns_3299W_Vertical').
Changed REF** reference designator to R11.
Changed R11 value from Potentiometer_Bourns_3299W_Vertical to 2k.
Updated R11 symbol association from  to /19e25b7f-f11f-43c6-9ca8-c0c99fb9a488/9f095502-74a7-4c81-92c6-8f6e65b1cef5.
Updated R11 fields.
Updated R11 sheetname to '/PowerSupplies/'.
Updated R11 sheetfile to 'ClockDistri.kicad_sch'.
Updated R11 footprint filters to 'R_*'.
Connected R11 pin 2 to GND.
Connected R11 pin 1 to Net-(U4-ADJ).
Updated C2 sheetfile to 'Freq_Reference.kicad_sch'.
Added R12 (footprint 'Resistor_SMD:R_1206_3216Metric_Pad1.30x1.75mm_HandSolder').
Changed REF** reference designator to R12.
Changed R12 value from R_1206_3216Metric_Pad1.30x1.75mm_HandSolder to 120R.
Updated R12 symbol association from  to /19e25b7f-f11f-43c6-9ca8-c0c99fb9a488/2c5dcf78-5f32-43bf-9df1-ca1c91397043.
Updated R12 fields.
Updated R12 sheetname to '/PowerSupplies/'.
Updated R12 sheetfile to 'ClockDistri.kicad_sch'.
Updated R12 footprint filters to 'R_*'.
Connected R12 pin 2 to Net-(U4-ADJ).
Connected R12 pin 1 to Net-(J8-Pin_1).
Updated C3 fields.
Added R13 (footprint 'Potentiometer_THT:Potentiometer_Bourns_3299W_Vertical').
Changed REF** reference designator to R13.
Changed R13 value from Potentiometer_Bourns_3299W_Vertical to 500R.
Updated R13 symbol association from  to /19e25b7f-f11f-43c6-9ca8-c0c99fb9a488/ba8300b8-081e-47a3-9af2-c1fbd1ee40db.
Updated R13 fields.
Updated R13 sheetname to '/PowerSupplies/'.
Updated R13 sheetfile to 'ClockDistri.kicad_sch'.
Updated R13 footprint filters to 'R_*'.
Connected R13 pin 2 to GND.
Connected R13 pin 1 to Net-(U7-ADJ).
Updated C3 sheetfile to 'Freq_Reference.kicad_sch'.
Added R14 (footprint 'Resistor_SMD:R_1206_3216Metric_Pad1.30x1.75mm_HandSolder').
Changed REF** reference designator to R14.
Changed R14 value from R_1206_3216Metric_Pad1.30x1.75mm_HandSolder to 120R.
Updated R14 symbol association from  to /19e25b7f-f11f-43c6-9ca8-c0c99fb9a488/1461d180-8939-4322-a0d1-4771d9087891.
Updated R14 fields.
Updated R14 sheetname to '/PowerSupplies/'.
Updated R14 sheetfile to 'ClockDistri.kicad_sch'.
Updated R14 footprint filters to 'R_*'.
Connected R14 pin 2 to Net-(U7-ADJ).
Connected R14 pin 1 to Net-(J8-Pin_7).
Updated C4 fields.
Added R15 (footprint 'Potentiometer_THT:Potentiometer_Bourns_3299W_Vertical').
Changed REF** reference designator to R15.
Changed R15 value from Potentiometer_Bourns_3299W_Vertical to 500R.
Updated R15 symbol association from  to /19e25b7f-f11f-43c6-9ca8-c0c99fb9a488/79875ab5-b78c-4798-9133-acde8f37abfe.
Updated R15 fields.
Updated R15 sheetname to '/PowerSupplies/'.
Updated R15 sheetfile to 'ClockDistri.kicad_sch'.
Updated R15 footprint filters to 'R_*'.
Connected R15 pin 1 to Net-(U8-ADJ).
Connected R15 pin 2 to GND.
Updated C4 sheetfile to 'Freq_Reference.kicad_sch'.
Added R16 (footprint 'Resistor_SMD:R_1206_3216Metric_Pad1.30x1.75mm_HandSolder').
Changed REF** reference designator to R16.
Changed R16 value from R_1206_3216Metric_Pad1.30x1.75mm_HandSolder to 120R.
Updated R16 symbol association from  to /19e25b7f-f11f-43c6-9ca8-c0c99fb9a488/4f77ee24-7054-49b4-b049-0a8cfd1645df.
Updated R16 fields.
Updated R16 sheetname to '/PowerSupplies/'.
Updated R16 sheetfile to 'ClockDistri.kicad_sch'.
Updated R16 footprint filters to 'R_*'.
Connected R16 pin 2 to Net-(U8-ADJ).
Connected R16 pin 1 to Net-(U8-VO).
Add net +15V.
Added R17 (footprint 'Resistor_SMD:R_1206_3216Metric_Pad1.30x1.75mm_HandSolder').
Changed REF** reference designator to R17.
Changed R17 value from R_1206_3216Metric_Pad1.30x1.75mm_HandSolder to 30.
Updated R17 symbol association from  to /f8bb9e2f-64b2-4dbf-b50c-25bc21bfe887.
Updated R17 fields.
Updated R17 sheetname to '/'.
Updated R17 sheetfile to 'Freq_Reference.kicad_sch'.
Updated R17 footprint filters to 'R_*'.
Add net Net-(U3-Q).
Connected R17 pin 1 to Net-(U3-Q).
Add net Net-(U9-CLK).
Connected R17 pin 2 to Net-(U9-CLK).
Reconnected C4 pin 1 from +9V to +15V.
Added R18 (footprint 'Resistor_SMD:R_1206_3216Metric_Pad1.30x1.75mm_HandSolder').
Changed REF** reference designator to R18.
Changed R18 value from R_1206_3216Metric_Pad1.30x1.75mm_HandSolder to 30.
Updated R18 symbol association from  to /d2ef6aa6-f48f-4ef7-a6b9-7930975ac0b3.
Updated R18 fields.
Updated R18 sheetname to '/'.
Updated R18 sheetfile to 'Freq_Reference.kicad_sch'.
Updated R18 footprint filters to 'R_*'.
Connected R18 pin 2 to Net-(J4-In).
Add net Net-(U9-Q2).
Connected R18 pin 1 to Net-(U9-Q2).
Updated C5 fields.
Added R19 (footprint 'Resistor_SMD:R_1206_3216Metric_Pad1.30x1.75mm_HandSolder').
Changed REF** reference designator to R19.
Changed R19 value from R_1206_3216Metric_Pad1.30x1.75mm_HandSolder to 30.
Updated R19 symbol association from  to /eef54ee8-f560-4a59-aeba-9e999d251004.
Updated R19 fields.
Updated R19 sheetname to '/'.
Updated R19 sheetfile to 'Freq_Reference.kicad_sch'.
Updated R19 footprint filters to 'R_*'.
Add net Net-(U9-Q3).
Connected R19 pin 1 to Net-(U9-Q3).
Connected R19 pin 2 to Net-(J7-In).
Updated C5 sheetfile to 'Freq_Reference.kicad_sch'.
Added R20 (footprint 'Resistor_SMD:R_1206_3216Metric_Pad1.30x1.75mm_HandSolder').
Changed REF** reference designator to R20.
Changed R20 value from R_1206_3216Metric_Pad1.30x1.75mm_HandSolder to 30.
Updated R20 symbol association from  to /4cbaa648-8351-40cd-bf67-d7b9e7d1db87.
Updated R20 fields.
Updated R20 sheetname to '/'.
Updated R20 sheetfile to 'Freq_Reference.kicad_sch'.
Updated R20 footprint filters to 'R_*'.
Add net Net-(U9-Q4).
Connected R20 pin 1 to Net-(U9-Q4).
Connected R20 pin 2 to Net-(J9-In).
Reconnected C5 pin 1 from +9V to +15V.
Added R21 (footprint 'Potentiometer_THT:Potentiometer_Bourns_3299W_Vertical').
Changed REF** reference designator to R21.
Changed R21 value from Potentiometer_Bourns_3299W_Vertical to 5k.
Updated R21 symbol association from  to /17e2898d-dbc4-4edd-8528-bc97c682181a.
Updated R21 fields.
Updated R21 sheetname to '/'.
Updated R21 sheetfile to 'Freq_Reference.kicad_sch'.
Updated R21 footprint filters to 'R_*'.
Connected R21 pin 1 to +5V.
Connected R21 pin 2 to Net-(Q1-B).
Added C6 (footprint 'Capacitor_SMD:C_1206_3216Metric_Pad1.33x1.80mm_HandSolder').
Added R22 (footprint 'Resistor_SMD:R_1206_3216Metric_Pad1.30x1.75mm_HandSolder').
Changed REF** reference designator to R22.
Changed R22 value from R_1206_3216Metric_Pad1.30x1.75mm_HandSolder to 100.
Updated R22 symbol association from  to /2400983a-de13-4d44-9245-3a946ab45ffa.
Updated R22 fields.
Updated R22 sheetname to '/'.
Updated R22 sheetfile to 'Freq_Reference.kicad_sch'.
Updated R22 footprint filters to 'R_*'.
Connected R22 pin 2 to GND.
Connected R22 pin 1 to Net-(U6-CLK).
Changed REF** reference designator to C6.
Added R23 (footprint 'Resistor_SMD:R_1206_3216Metric_Pad1.30x1.75mm_HandSolder').
Changed REF** reference designator to R23.
Changed R23 value from R_1206_3216Metric_Pad1.30x1.75mm_HandSolder to 100.
Updated R23 symbol association from  to /a82da336-963b-49f2-974b-220bce353083.
Updated R23 fields.
Updated R23 sheetname to '/'.
Updated R23 sheetfile to 'Freq_Reference.kicad_sch'.
Updated R23 footprint filters to 'R_*'.
Connected R23 pin 2 to Net-(U6-CLK).
Connected R23 pin 1 to Net-(Q2-E).
Changed C6 value from C_1206_3216Metric_Pad1.33x1.80mm_HandSolder to 10nF.
Added R24 (footprint 'Resistor_SMD:R_1206_3216Metric_Pad1.30x1.75mm_HandSolder').
Changed REF** reference designator to R24.
Changed R24 value from R_1206_3216Metric_Pad1.30x1.75mm_HandSolder to 30.
Updated R24 symbol association from  to /fac4d82f-7845-4cb5-815d-3ba76260e9cc.
Updated R24 fields.
Updated R24 sheetname to '/'.
Updated R24 sheetfile to 'Freq_Reference.kicad_sch'.
Updated R24 footprint filters to 'R_*'.
Connected R24 pin 2 to Net-(J3-In).
Add net Net-(U6-Q1).
Connected R24 pin 1 to Net-(U6-Q1).
Updated C6 symbol association from  to /d1a766f2-bb37-40f9-ab35-6aed6843619b.
Added R25 (footprint 'Resistor_SMD:R_1206_3216Metric_Pad1.30x1.75mm_HandSolder').
Changed REF** reference designator to R25.
Changed R25 value from R_1206_3216Metric_Pad1.30x1.75mm_HandSolder to 30.
Updated R25 symbol association from  to /a49cd506-79aa-46ab-8931-ca49feae9aea.
Updated R25 fields.
Updated R25 sheetname to '/'.
Updated R25 sheetfile to 'Freq_Reference.kicad_sch'.
Updated R25 footprint filters to 'R_*'.
Connected R25 pin 2 to Net-(J10-In).
Add net Net-(U6-Q2).
Connected R25 pin 1 to Net-(U6-Q2).
Updated C6 fields.
Added R26 (footprint 'Resistor_SMD:R_1206_3216Metric_Pad1.30x1.75mm_HandSolder').
Changed REF** reference designator to R26.
Changed R26 value from R_1206_3216Metric_Pad1.30x1.75mm_HandSolder to 30.
Updated R26 symbol association from  to /2ebf8769-a751-4c5c-ad42-c9cae65799f1.
Updated R26 fields.
Updated R26 sheetname to '/'.
Updated R26 sheetfile to 'Freq_Reference.kicad_sch'.
Updated R26 footprint filters to 'R_*'.
Connected R26 pin 2 to Net-(J11-In).
Add net Net-(U6-Q3).
Connected R26 pin 1 to Net-(U6-Q3).
Updated C6 sheetname to '/'.
Added R27 (footprint 'Resistor_SMD:R_1206_3216Metric_Pad1.30x1.75mm_HandSolder').
Changed REF** reference designator to R27.
Changed R27 value from R_1206_3216Metric_Pad1.30x1.75mm_HandSolder to 30.
Updated R27 symbol association from  to /8442f091-cdbb-41f2-aeff-c4f7fcf43c99.
Updated C6 sheetfile to 'Freq_Reference.kicad_sch'.
Updated R27 sheetname to '/'.
Updated R27 sheetfile to 'Freq_Reference.kicad_sch'.
Updated R27 footprint filters to 'R_*'.
Add net Net-(U6-Q4).
Connected R27 pin 1 to Net-(U6-Q4).
Connected R27 pin 2 to Net-(J12-In).
Updated C6 footprint filters to 'C_*'.
Added R28 (footprint 'Resistor_SMD:R_1206_3216Metric_Pad1.30x1.75mm_HandSolder').
Changed REF** reference designator to R28.
Changed R28 value from R_1206_3216Metric_Pad1.30x1.75mm_HandSolder to 5k1.
Updated R28 symbol association from  to /b76283ca-19ca-419d-826e-d17f55a6df4d.
Updated R28 fields.
Updated R28 sheetname to '/'.
Updated R28 sheetfile to 'Freq_Reference.kicad_sch'.
Updated R28 footprint filters to 'R_*'.
Connected R28 pin 2 to Net-(Q2-B).
Connected R28 pin 1 to GND.
Add net Net-(U6-CLK).
Added R29 (footprint 'Potentiometer_THT:Potentiometer_Bourns_3299W_Vertical').
Changed REF** reference designator to R29.
Changed R29 value from Potentiometer_Bourns_3299W_Vertical to 5k.
Updated R29 symbol association from  to /204caebd-c26f-4f19-91cb-5fbb5c5af13b.
Updated R29 fields.
Updated R29 sheetname to '/'.
Updated R29 sheetfile to 'Freq_Reference.kicad_sch'.
Updated R29 footprint filters to 'R_*'.
Connected R29 pin 1 to +5V.
Connected R29 pin 2 to Net-(Q2-B).
Connected C6 pin 2 to Net-(U6-CLK).
Added R30 (footprint 'Resistor_SMD:R_1206_3216Metric_Pad1.30x1.75mm_HandSolder').
Changed REF** reference designator to R30.
Changed R30 value from R_1206_3216Metric_Pad1.30x1.75mm_HandSolder to 00.
Updated R30 symbol association from  to /19e25b7f-f11f-43c6-9ca8-c0c99fb9a488/ab1709e0-38e5-465a-ad3c-6d5d85a77e77.
Updated R30 fields.
Updated R30 sheetname to '/PowerSupplies/'.
Updated R30 sheetfile to 'ClockDistri.kicad_sch'.
Updated R30 footprint filters to 'R_*'.
Connected R30 pin 1 to Net-(J8-Pin_1).
Connected R30 pin 2 to +15V.
Add net Net-(J13-In).
Added R31 (footprint 'Resistor_SMD:R_1206_3216Metric_Pad1.30x1.75mm_HandSolder').
Changed REF** reference designator to R31.
Changed R31 value from R_1206_3216Metric_Pad1.30x1.75mm_HandSolder to 00.
Updated R31 symbol association from  to /19e25b7f-f11f-43c6-9ca8-c0c99fb9a488/a2503d3e-29d6-406f-90fa-f77f7a55ec21.
Updated R31 fields.
Updated R31 sheetname to '/PowerSupplies/'.
Updated R31 sheetfile to 'ClockDistri.kicad_sch'.
Updated R31 footprint filters to 'R_*'.
Connected R31 pin 2 to +5V.
Connected R31 pin 1 to Net-(J8-Pin_7).
Connected C6 pin 1 to Net-(J13-In).
Added R32 (footprint 'Resistor_SMD:R_1206_3216Metric_Pad1.30x1.75mm_HandSolder').
Changed REF** reference designator to R32.
Changed R32 value from R_1206_3216Metric_Pad1.30x1.75mm_HandSolder to 00.
Updated R32 symbol association from  to /19e25b7f-f11f-43c6-9ca8-c0c99fb9a488/f8560300-622d-48b2-9918-640531584be9.
Updated R32 fields.
Updated R32 sheetname to '/PowerSupplies/'.
Updated R32 sheetfile to 'ClockDistri.kicad_sch'.
Updated R32 footprint filters to 'R_*'.
Connected R32 pin 1 to Net-(U8-VO).
Connected R32 pin 2 to +3.3V.
Added C7 (footprint 'Capacitor_SMD:C_1206_3216Metric_Pad1.33x1.80mm_HandSolder').
Added TP1 (footprint 'TestPoint:TestPoint_Plated_Hole_D2.0mm').
Changed REF** reference designator to TP1.
Changed TP1 value from TestPoint_Plated_Hole_D2.0mm to +15V.
Updated TP1 symbol association from  to /19e25b7f-f11f-43c6-9ca8-c0c99fb9a488/b559c4a0-e599-41b5-9fdc-2c10182d6456.
Updated TP1 fields.
Updated TP1 sheetname to '/PowerSupplies/'.
Updated TP1 sheetfile to 'ClockDistri.kicad_sch'.
Updated TP1 footprint filters to 'Pin* Test*'.
Removed TP1 'exclude from BOM' fabrication attribute.
Connected TP1 pin 1 to Net-(J8-Pin_1).
Changed REF** reference designator to C7.
Added TP2 (footprint 'TestPoint:TestPoint_Plated_Hole_D2.0mm').
Changed REF** reference designator to TP2.
Changed TP2 value from TestPoint_Plated_Hole_D2.0mm to +5V.
Updated TP2 symbol association from  to /19e25b7f-f11f-43c6-9ca8-c0c99fb9a488/9e82f73d-3a91-42ad-a86a-2ba7c93816aa.
Updated TP2 fields.
Updated TP2 sheetname to '/PowerSupplies/'.
Updated TP2 sheetfile to 'ClockDistri.kicad_sch'.
Updated TP2 footprint filters to 'Pin* Test*'.
Removed TP2 'exclude from BOM' fabrication attribute.
Connected TP2 pin 1 to Net-(J8-Pin_7).
Changed C7 value from C_1206_3216Metric_Pad1.33x1.80mm_HandSolder to 100nF.
Added TP3 (footprint 'TestPoint:TestPoint_Plated_Hole_D2.0mm').
Changed REF** reference designator to TP3.
Changed TP3 value from TestPoint_Plated_Hole_D2.0mm to Gnd.
Updated TP3 symbol association from  to /19e25b7f-f11f-43c6-9ca8-c0c99fb9a488/7a470070-329f-46d1-a90a-3c5f51e8b85d.
Updated TP3 fields.
Updated TP3 sheetname to '/PowerSupplies/'.
Updated TP3 sheetfile to 'ClockDistri.kicad_sch'.
Updated TP3 footprint filters to 'Pin* Test*'.
Removed TP3 'exclude from BOM' fabrication attribute.
Connected TP3 pin 1 to GND.
Updated C7 symbol association from  to /986afb7f-b909-4b55-817e-f135b378ed3c.
Added TP4 (footprint 'TestPoint:TestPoint_Plated_Hole_D2.0mm').
Changed REF** reference designator to TP4.
Changed TP4 value from TestPoint_Plated_Hole_D2.0mm to +3V.
Updated TP4 symbol association from  to /19e25b7f-f11f-43c6-9ca8-c0c99fb9a488/d676fcfd-24d2-4b6e-9855-6281220a4857.
Updated TP4 fields.
Updated TP4 sheetname to '/PowerSupplies/'.
Updated TP4 sheetfile to 'ClockDistri.kicad_sch'.
Updated TP4 footprint filters to 'Pin* Test*'.
Removed TP4 'exclude from BOM' fabrication attribute.
Connected TP4 pin 1 to Net-(U8-VO).
Updated C7 fields.
Added TP5 (footprint 'TestPoint:TestPoint_Plated_Hole_D2.0mm').
Changed REF** reference designator to TP5.
Changed TP5 value from TestPoint_Plated_Hole_D2.0mm to MHZ50_A.
Updated TP5 symbol association from  to /85088126-1986-4184-9b41-191ed40b0a46.
Updated TP5 fields.
Updated TP5 sheetname to '/'.
Updated TP5 sheetfile to 'Freq_Reference.kicad_sch'.
Updated TP5 footprint filters to 'Pin* Test*'.
Removed TP5 'exclude from BOM' fabrication attribute.
Connected TP5 pin 1 to Net-(R6-Pad2).
Updated C7 sheetname to '/'.
Updated R27 fields.
Changed REF** reference designator to TP6.
Changed TP6 value from TestPoint_Plated_Hole_D2.0mm to MHZ50_B.
Updated TP6 symbol association from  to /d5d7c96a-f472-4a41-8a62-1cf01dbdb6b4.
Updated TP6 fields.
Updated TP6 sheetname to '/'.
Updated TP6 sheetfile to 'Freq_Reference.kicad_sch'.
Updated TP6 footprint filters to 'Pin* Test*'.
Removed TP6 'exclude from BOM' fabrication attribute.
Connected TP6 pin 1 to Net-(R7-Pad2).
Updated C7 sheetfile to 'Freq_Reference.kicad_sch'.
Added TP7 (footprint 'TestPoint:TestPoint_Plated_Hole_D2.0mm').
Changed REF** reference designator to TP7.
Changed TP7 value from TestPoint_Plated_Hole_D2.0mm to Gnd.
Updated TP7 symbol association from  to /fcc2a8d8-1d32-4a3b-af5a-3ebba7561dac.
Updated TP7 fields.
Updated TP7 sheetname to '/'.
Updated TP7 sheetfile to 'Freq_Reference.kicad_sch'.
Updated TP7 footprint filters to 'Pin* Test*'.
Removed TP7 'exclude from BOM' fabrication attribute.
Connected TP7 pin 1 to GND.
Updated C7 footprint filters to 'C_*'.
Added TP8 (footprint 'TestPoint:TestPoint_Plated_Hole_D2.0mm').
Changed REF** reference designator to TP8.
Changed TP8 value from TestPoint_Plated_Hole_D2.0mm to Gnd.
Updated TP8 symbol association from  to /48c83390-f97b-45ec-9ae5-c7b2d4c0a631.
Updated TP8 fields.
Updated TP8 sheetname to '/'.
Updated TP8 sheetfile to 'Freq_Reference.kicad_sch'.
Updated TP8 footprint filters to 'Pin* Test*'.
Removed TP8 'exclude from BOM' fabrication attribute.
Connected TP8 pin 1 to GND.
Connected C7 pin 2 to GND.
Changed U1 value from 3 to 1.
Updated U1 sheetfile to 'Freq_Reference.kicad_sch'.
Add net Net-(Q1-B).
Changed U2 value from 4 to 5.
Updated U2 sheetfile to 'Freq_Reference.kicad_sch'.
Connected C7 pin 1 to Net-(Q1-B).
Updated U3 sheetfile to 'Freq_Reference.kicad_sch'.
Reconnected U3 pin 5 from Net-(J2-In) to Net-(U3-Q).
Added C8 (footprint 'Capacitor_SMD:C_1206_3216Metric_Pad1.33x1.80mm_HandSolder').
Added U4 (footprint 'Package_TO_SOT_SMD:TO-263-3_TabPin2').
Changed REF** reference designator to U4.
Changed U4 value from TO-263-3_TabPin2 to LT1085-ADJ.
Updated U4 symbol association from  to /19e25b7f-f11f-43c6-9ca8-c0c99fb9a488/6a7f7518-4780-41fa-a1a3-b3b84effe205.
Updated U4 fields.
Updated U4 sheetname to '/PowerSupplies/'.
Updated U4 sheetfile to 'ClockDistri.kicad_sch'.
Updated U4 footprint filters to 'TO?220* TO?263*'.
Connected U4 pin 3 to VBUS.
Connected U4 pin 2 to Net-(J8-Pin_1).
Connected U4 pin 1 to Net-(U4-ADJ).
Connected U4 pin 2 to Net-(J8-Pin_1).
Changed REF** reference designator to C8.
Updated U5 sheetfile to 'Freq_Reference.kicad_sch'.
Changed C8 value from C_1206_3216Metric_Pad1.33x1.80mm_HandSolder to 10uF.
Added U6 (footprint 'Package_SO:SOIC-8_5.3x6.2mm_P1.27mm').
Changed REF** reference designator to U6.
Changed U6 value from SOIC-8_5.3x6.2mm_P1.27mm to 551MLFT.
Updated U6 symbol association from  to /23898745-c3fc-4f2a-95db-b6555cdfe8aa.
Updated U6 sheetname to '/'.
Updated U6 sheetfile to 'Freq_Reference.kicad_sch'.
Connected U6 pin 8 to +3.3V.
Connected U6 pin 5 to Net-(U6-Q4).
Connected U6 pin 3 to Net-(U6-Q2).
Connected U6 pin 1 to Net-(U6-CLK).
Connected U6 pin 2 to Net-(U6-Q1).
Connected U6 pin 7 to +3.3V.
Connected U6 pin 4 to Net-(U6-Q3).
Connected U6 pin 6 to GND.
Updated C8 symbol association from  to /19e25b7f-f11f-43c6-9ca8-c0c99fb9a488/65cc2aa5-a631-48e4-bcfd-5543aeace756.
Added U7 (footprint 'Package_TO_SOT_SMD:TO-263-3_TabPin2').
Changed REF** reference designator to U7.
Changed U7 value from TO-263-3_TabPin2 to LT1085-ADJ.
Updated U7 symbol association from  to /19e25b7f-f11f-43c6-9ca8-c0c99fb9a488/07429a21-599b-4f7b-a509-347eb9751372.
Updated U7 fields.
Updated U7 sheetname to '/PowerSupplies/'.
Updated U7 sheetfile to 'ClockDistri.kicad_sch'.
Updated U7 footprint filters to 'TO?220* TO?263*'.
Connected U7 pin 2 to Net-(J8-Pin_7).
Connected U7 pin 3 to VBUS.
Connected U7 pin 1 to Net-(U7-ADJ).
Connected U7 pin 2 to Net-(J8-Pin_7).
Updated C8 fields.
Added U8 (footprint 'Package_TO_SOT_SMD:TO-263-3_TabPin2').
Changed REF** reference designator to U8.
Changed U8 value from TO-263-3_TabPin2 to LT1085-ADJ.
Updated U8 symbol association from  to /19e25b7f-f11f-43c6-9ca8-c0c99fb9a488/7d838a64-ff96-47f8-b554-4fec1e037e10.
Updated U8 fields.
Updated U8 sheetname to '/PowerSupplies/'.
Updated U8 sheetfile to 'ClockDistri.kicad_sch'.
Updated U8 footprint filters to 'TO?220* TO?263*'.
Connected U8 pin 3 to Net-(J8-Pin_7).
Connected U8 pin 2 to Net-(U8-VO).
Connected U8 pin 2 to Net-(U8-VO).
Connected U8 pin 1 to Net-(U8-ADJ).
Updated C8 sheetname to '/PowerSupplies/'.
Added U9 (footprint 'Package_SO:SOIC-8_5.3x6.2mm_P1.27mm').
Changed REF** reference designator to U9.
Changed U9 value from SOIC-8_5.3x6.2mm_P1.27mm to 551MLFT.
Updated U9 symbol association from  to /96e8de21-914d-49f0-b7e1-d58ad571b5db.
Updated U9 sheetname to '/'.
Updated U9 sheetfile to 'Freq_Reference.kicad_sch'.
Connected U9 pin 4 to Net-(U9-Q3).
Connected U9 pin 2 to Net-(U9-Q1).
Connected U9 pin 7 to +3.3V.
Connected U9 pin 3 to Net-(U9-Q2).
Connected U9 pin 8 to +3.3V.
Connected U9 pin 1 to Net-(U9-CLK).
Connected U9 pin 5 to Net-(U9-Q4).
Connected U9 pin 6 to GND.
Removed unused footprint U6.
Removed unused footprint J3.
Removed unused footprint L1.
Removed unused footprint C6.
Removed unused footprint J5.

Added TP6 (footprint 'TestPoint:TestPoint_Plated_Hole_D2.0mm').
Warning: No net found for component L1 pad 4 (no pin 4 in symbol).
Warning: No net found for component R13 pad 3 (no pin 3 in symbol).
Warning: No net found for component L2 pad 4 (no pin 4 in symbol).
Warning: No net found for component R11 pad 3 (no pin 3 in symbol).
Warning: No net found for component J5 pad 3 (no pin 3 in symbol).
Warning: No net found for component R29 pad 3 (no pin 3 in symbol).
Warning: No net found for component R15 pad 3 (no pin 3 in symbol).
Warning: No net found for component L1 pad 2 (no pin 2 in symbol).
Warning: No net found for component R21 pad 3 (no pin 3 in symbol).

Info: Total warnings: 9, errors: 0.

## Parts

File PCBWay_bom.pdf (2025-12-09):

PCBWay_bom

Designator | Quantity Value
C1, C14, C15, C16 | 4 | 10nF
C10, C7, C9 | 3 | 22uF
C11, C24, C6 | 3 | 47uF
| 14 | 39nF
C13, C17 | 2 | 1uF
C19, C2, C21, C23 | 4 | 100nF
C25 | 1 | 10uF
D1, D2 | 2 | LED
J1, J2, J3 | 3 | MHz 10
J10, J11, J12, J9 | 4 | MHz 25
J13 | 1 | MHz 50
J4 | 1 | MHz 10 Source
J5 | 1 | MHz 10 LPF
J6 | 1 | Conn_02x07_Odd_Even
J7 | 1 | MHz 50 LPF
J8 | 1 | Jack-DC
L1, L2 | 2 | TCCH-80+
Logo1 | 1 | LOGO
Q1, Q2 | 2 | 2N2222
R1 | 1 | 220R
R10, R14, R22 | 3 | 0
| 13 | 30
R12, R17 | 2 | 500R
R13, R16, R18 | 3 | 120R
R15 | 1 | 2k
R19 | 1 | 300
R2 | 1 | 330R
R20 | 1 | 160
R21, R3, R30, R6 | 4 | 100
R23, R5 | 2 | 5k
R24, R9 | 2 | 5k1
TP1 | 1 | MHZ50_A
TP2, TP3, TP_GND1 | 3 | Gnd
TP4 | 1 | MHZ50_B
TP_P15V1 | 1 | +15V
TP_P3V3 | 1 | +3.3V
TP_P5V1 | 1 | +5V
TP_VBUS1 | 1 | +16V
U1, U8, U9 | 3 | 551MLFT
U2, U3, U6 | 3 | LT1085-ADJ
U4 | 1 | ERA-1SM+
U5 | 1 | ERA-5SM+
U7 | 1 | 74LVC74

C12, C18, C20, C22, C26,
C27, C28, C29, C3, C30,
C31, C4, C5, C8

R11, R25, R26, R27, R28,
R29, R31, R32, R33, R34,
R4, R7, R8

Footprint | Mount_Type
C_1206_3216Metric_Pad1.33x1.80mm_HandSolder smt
CP_EIA-7343-31_Kemet-D_HandSolder | smt
CP_EIA-7343-31_Kemet-D_HandSolder | smt

C_1206_3216Metric_Pad1.33x1.80mm_HandSolder smt

C_1206_3216Metric_Pad1.33x1.80mm_HandSolder smt C_1206_3216Metric_Pad1.33x1.80mm_HandSolder smt
CP_EIA-7343-31_Kemet-D_HandSolder | smt
LED_D3.0mm | tht
SMA_Amphenol_132289_EdgeMount | smt
SMA_Amphenol_132289_EdgeMount | smt
SMA_Amphenol_132289_EdgeMount | smt
SMA_Amphenol_132289_EdgeMount | smt
SMA_Amphenol_132134-11_Vertical | tht
PinHeader_2x07_P2.54mm_Vertical | tht
SMA_Amphenol_132134-11_Vertical | tht
BarrelJack_Horizontal | tht
Minicircuits_GU1604 | smt
F4LHU | tht
TO-92_Inline_Wide | tht
R_1206_3216Metric_Pad1.30x1.75mm_HandSolder smt R_1206_3216Metric_Pad1.30x1.75mm_HandSolder smt

R_1206_3216Metric_Pad1.30x1.75mm_HandSolder smt

Potentiometer_Bourns_3299W_Vertical | tht
R_1206_3216Metric_Pad1.30x1.75mm_HandSolder smt
Potentiometer_Bourns_3299W_Vertical | tht
R_2512_6332Metric_Pad1.40x3.35mm_HandSolder smt R_1206_3216Metric_Pad1.30x1.75mm_HandSolder smt R_2512_6332Metric_Pad1.40x3.35mm_HandSolder smt R_1206_3216Metric_Pad1.30x1.75mm_HandSolder smt
Potentiometer_Bourns_3299W_Vertical | tht
R_1206_3216Metric_Pad1.30x1.75mm_HandSolder smt
TestPoint_THTPad_1.5x1.5mm_Drill0.7mm | tht
TestPoint_THTPad_1.5x1.5mm_Drill0.7mm | tht
TestPoint_THTPad_1.5x1.5mm_Drill0.7mm | tht
TestPoint_THTPad_1.5x1.5mm_Drill0.7mm | tht
TestPoint_THTPad_1.5x1.5mm_Drill0.7mm | tht
TestPoint_THTPad_1.5x1.5mm_Drill0.7mm | tht
TestPoint_THTPad_1.5x1.5mm_Drill0.7mm | tht
SOIC-8_5.3x6.2mm_P1.27mm | smt
TO-220-3_Vertical | tht
WW107 | smt
WW107 | smt
SSOP-8_2.95x2.8mm_P0.65mm | smt

Description | Sim.Pins
Unpolarized capacitor
Polarized capacitor, small symbol
Polarized capacitor, small symbol

Unpolarized capacitor

Unpolarized capacitor
Unpolarized capacitor
Polarized capacitor, small symbol
Light emitting diode | 1=K 2=A
small coaxial connector (BNC, SMA, SMB, SMC, Cinch/RCA, LEMO, ...)
small coaxial connector (BNC, SMA, SMB, SMC, Cinch/RCA, LEMO, ...)
small coaxial connector (BNC, SMA, SMB, SMC, Cinch/RCA, LEMO, ...)
small coaxial connector (BNC, SMA, SMB, SMC, Cinch/RCA, LEMO, ...) small coaxial connector (BNC, SMA, SMB, SMC, Cinch/RCA, LEMO, ...)

small coaxial connector (BNC, SMA, SMB, SMC, Cinch/RCA, LEMO, ...) DC Barrel Jack
Inductor
Logo F4LHU
0.2A Ic, 40V Vce, Small Signal NPN Transistor, TO-92 Resistor
Resistor

Resistor

Trimmable resistor (preset resistor) Resistor
Trimmable resistor (preset resistor) Resistor
Resistor
Resistor
Resistor
Trimmable resistor (preset resistor) Resistor
test point
test point
test point
test point
test point
test point
test point

3.0A 25V LDO Linear Regulator, Adjustable Output, TO-220/TO-263

Generic connector, double row, 02x07, odd/even pin numbering scheme (row 1 odd numbers, row 2 even numbers), script generated (kicad-library-utils/schlib/autogen/connector/)

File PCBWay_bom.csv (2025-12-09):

Designator | Quantity | Value | Footprint | Package | MPN | DNP | Mount_Type | Description | Sim.Pins
C1, C14, C15, C16 | 4 | 10nF | C_1206_3216Metric_Pad1.33x1.80mm_HandSolder |  |  |  | smt | Unpolarized capacitor
C10, C7, C9 | 3 | 22uF | CP_EIA-7343-31_Kemet-D_HandSolder |  |  |  | smt | Polarized capacitor, small symbol
C11, C24, C6 | 3 | 47uF | CP_EIA-7343-31_Kemet-D_HandSolder |  |  |  | smt | Polarized capacitor, small symbol
C12, C18, C20, C22, C26, C27, C28, C29, C3, C30, C31, C4, C5, C8 | 14 | 39nF | C_1206_3216Metric_Pad1.33x1.80mm_HandSolder |  |  |  | smt | Unpolarized capacitor
C13, C17 | 2 | 1uF | C_1206_3216Metric_Pad1.33x1.80mm_HandSolder |  |  |  | smt | Unpolarized capacitor
C19, C2, C21, C23 | 4 | 100nF | C_1206_3216Metric_Pad1.33x1.80mm_HandSolder |  |  |  | smt | Unpolarized capacitor
C25 | 1 | 10uF | CP_EIA-7343-31_Kemet-D_HandSolder |  |  |  | smt | Polarized capacitor, small symbol
D1, D2 | 2 | LED | LED_D3.0mm |  |  |  | tht | Light emitting diode | 1=K 2=A
J1, J2, J3 | 3 | MHz 10 | SMA_Amphenol_132289_EdgeMount |  |  |  | smt | small coaxial connector (BNC, SMA, SMB, SMC, Cinch/RCA, LEMO, ...)
J10, J11, J12, J9 | 4 | MHz 25 | SMA_Amphenol_132289_EdgeMount |  |  |  | smt | small coaxial connector (BNC, SMA, SMB, SMC, Cinch/RCA, LEMO, ...)
J13 | 1 | MHz 50 | SMA_Amphenol_132289_EdgeMount |  |  |  | smt | small coaxial connector (BNC, SMA, SMB, SMC, Cinch/RCA, LEMO, ...)
J4 | 1 | MHz 10 Source | SMA_Amphenol_132289_EdgeMount |  |  |  | smt | small coaxial connector (BNC, SMA, SMB, SMC, Cinch/RCA, LEMO, ...)
J5 | 1 | MHz 10 LPF | SMA_Amphenol_132134-11_Vertical |  |  |  | tht | small coaxial connector (BNC, SMA, SMB, SMC, Cinch/RCA, LEMO, ...)
J6 | 1 | Conn_02x07_Odd_Even | PinHeader_2x07_P2.54mm_Vertical |  |  |  | tht | Generic connector, double row, 02x07, odd/even pin numbering scheme (row 1 odd numbers, row 2 even numbers), script generated (kicad-library-utils/schlib/autogen/connector/)
J7 | 1 | MHz 50 LPF | SMA_Amphenol_132134-11_Vertical |  |  |  | tht | small coaxial connector (BNC, SMA, SMB, SMC, Cinch/RCA, LEMO, ...)
J8 | 1 | Jack-DC | BarrelJack_Horizontal |  |  |  | tht | DC Barrel Jack
L1, L2 | 2 | TCCH-80+ | Minicircuits_GU1604 |  |  |  | smt | Inductor
Logo1 | 1 | LOGO | F4LHU |  |  |  | tht | Logo F4LHU
Q1, Q2 | 2 | 2N2222 | TO-92_Inline_Wide |  |  |  | tht | 0.2A Ic, 40V Vce, Small Signal NPN Transistor, TO-92
R1 | 1 | 220R | R_1206_3216Metric_Pad1.30x1.75mm_HandSolder |  |  |  | smt | Resistor
R10, R14, R22 | 3 | 00 | R_1206_3216Metric_Pad1.30x1.75mm_HandSolder |  |  |  | smt | Resistor
R11, R25, R26, R27, R28, R29, R31, R32, R33, R34, R4, R7, R8 | 13 | 30 | R_1206_3216Metric_Pad1.30x1.75mm_HandSolder |  |  |  | smt | Resistor
R12, R17 | 2 | 500R | Potentiometer_Bourns_3299W_Vertical |  |  |  | tht | Trimmable resistor (preset resistor)
R13, R16, R18 | 3 | 120R | R_1206_3216Metric_Pad1.30x1.75mm_HandSolder |  |  |  | smt | Resistor
R15 | 1 | 2k | Potentiometer_Bourns_3299W_Vertical |  |  |  | tht | Trimmable resistor (preset resistor)
R19 | 1 | 300 | R_2512_6332Metric_Pad1.40x3.35mm_HandSolder |  |  |  | smt | Resistor
R2 | 1 | 330R | R_1206_3216Metric_Pad1.30x1.75mm_HandSolder |  |  |  | smt | Resistor
R20 | 1 | 160 | R_2512_6332Metric_Pad1.40x3.35mm_HandSolder |  |  |  | smt | Resistor
R21, R3, R30, R6 | 4 | 100 | R_1206_3216Metric_Pad1.30x1.75mm_HandSolder |  |  |  | smt | Resistor
R23, R5 | 2 | 5k | Potentiometer_Bourns_3299W_Vertical |  |  |  | tht | Trimmable resistor (preset resistor)
R24, R9 | 2 | 5k1 | R_1206_3216Metric_Pad1.30x1.75mm_HandSolder |  |  |  | smt | Resistor
TP1 | 1 | MHZ50_A | TestPoint_THTPad_1.5x1.5mm_Drill0.7mm |  |  |  | tht | test point
TP2, TP3, TP_GND1 | 3 | Gnd | TestPoint_THTPad_1.5x1.5mm_Drill0.7mm |  |  |  | tht | test point
TP4 | 1 | MHZ50_B | TestPoint_THTPad_1.5x1.5mm_Drill0.7mm |  |  |  | tht | test point
TP_P15V1 | 1 | +15V | TestPoint_THTPad_1.5x1.5mm_Drill0.7mm |  |  |  | tht | test point
TP_P3V3 | 1 | +3.3V | TestPoint_THTPad_1.5x1.5mm_Drill0.7mm |  |  |  | tht | test point
TP_P5V1 | 1 | +5V | TestPoint_THTPad_1.5x1.5mm_Drill0.7mm |  |  |  | tht | test point
TP_VBUS1 | 1 | +16V | TestPoint_THTPad_1.5x1.5mm_Drill0.7mm |  |  |  | tht | test point
U1, U8, U9 | 3 | 551MLFT | SOIC-8_5.3x6.2mm_P1.27mm |  |  |  | smt
U2, U3, U6 | 3 | LT1085-ADJ | TO-220-3_Vertical |  |  |  | tht | 3.0A 25V LDO Linear Regulator, Adjustable Output, TO-220/TO-263
U4 | 1 | ERA-1SM+ | WW107 |  |  |  | smt
U5 | 1 | ERA-5SM+ | WW107 |  |  |  | smt
U7 | 1 | 74LVC74 | SSOP-8_2.95x2.8mm_P0.65mm |  |  |  | smt

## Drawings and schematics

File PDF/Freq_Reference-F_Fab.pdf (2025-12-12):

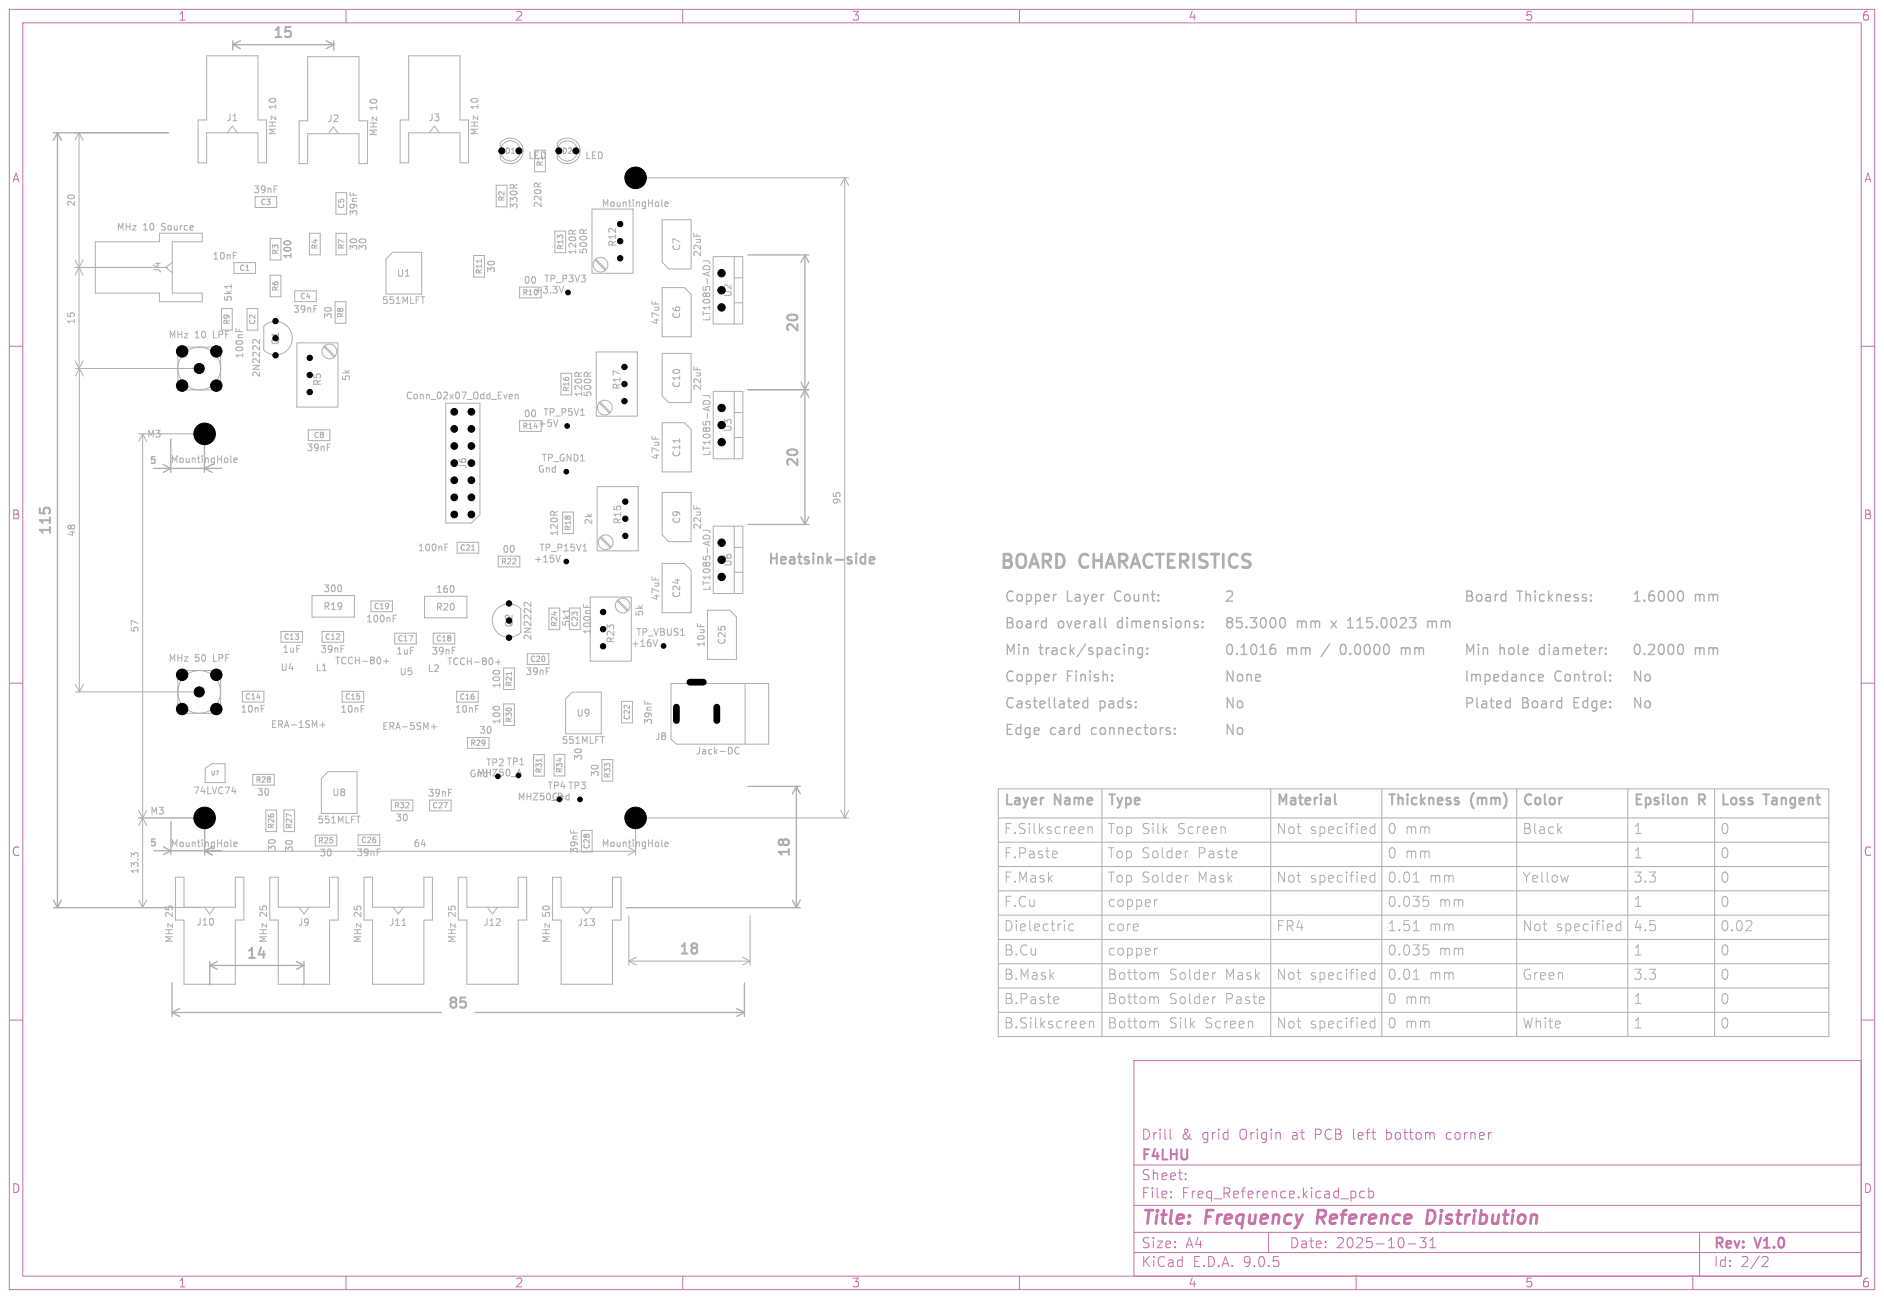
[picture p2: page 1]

Top Silk Screen | Not specified | White Dielectric Not specified B.Paste | 0 No

Bottom Solder Mask Type | | | | 0 mm | | Loss Tangent 0

0.035 mm | | 0 F.Paste

Screen | | | | | 3.3 Bottom Silk 4.5

0 mm | 1 Not specified | 0

Id: 2/2 Title: Frequency Reference Distribution

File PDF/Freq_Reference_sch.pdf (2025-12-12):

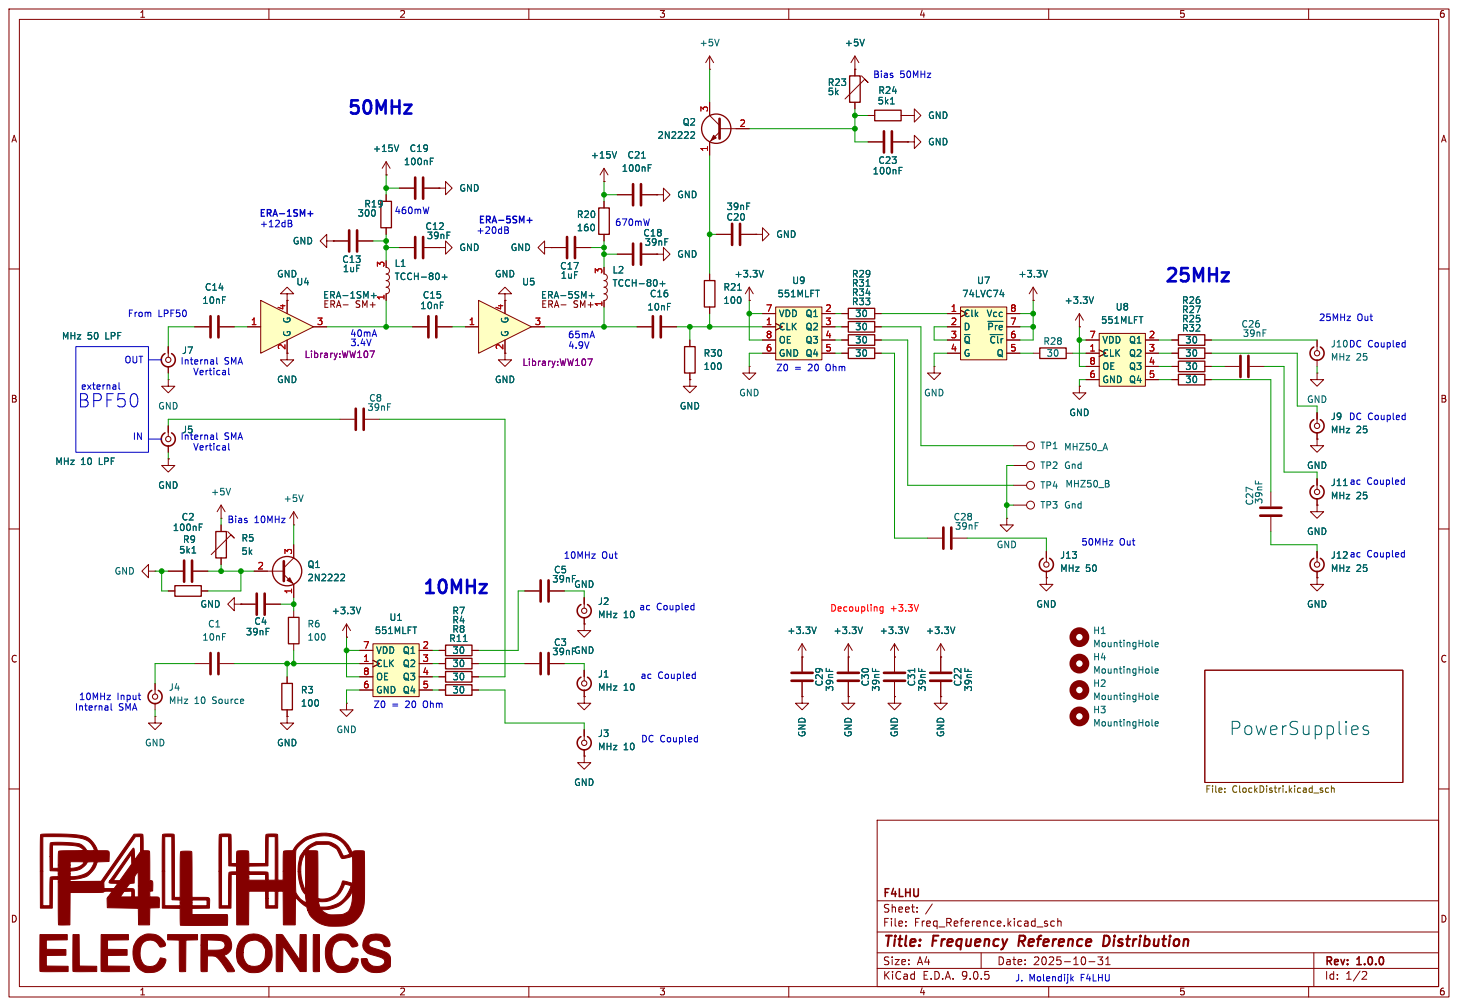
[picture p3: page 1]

J12 MHz 25 GND GND GND

Id: 1/2 Title: Frequency Reference Distribution

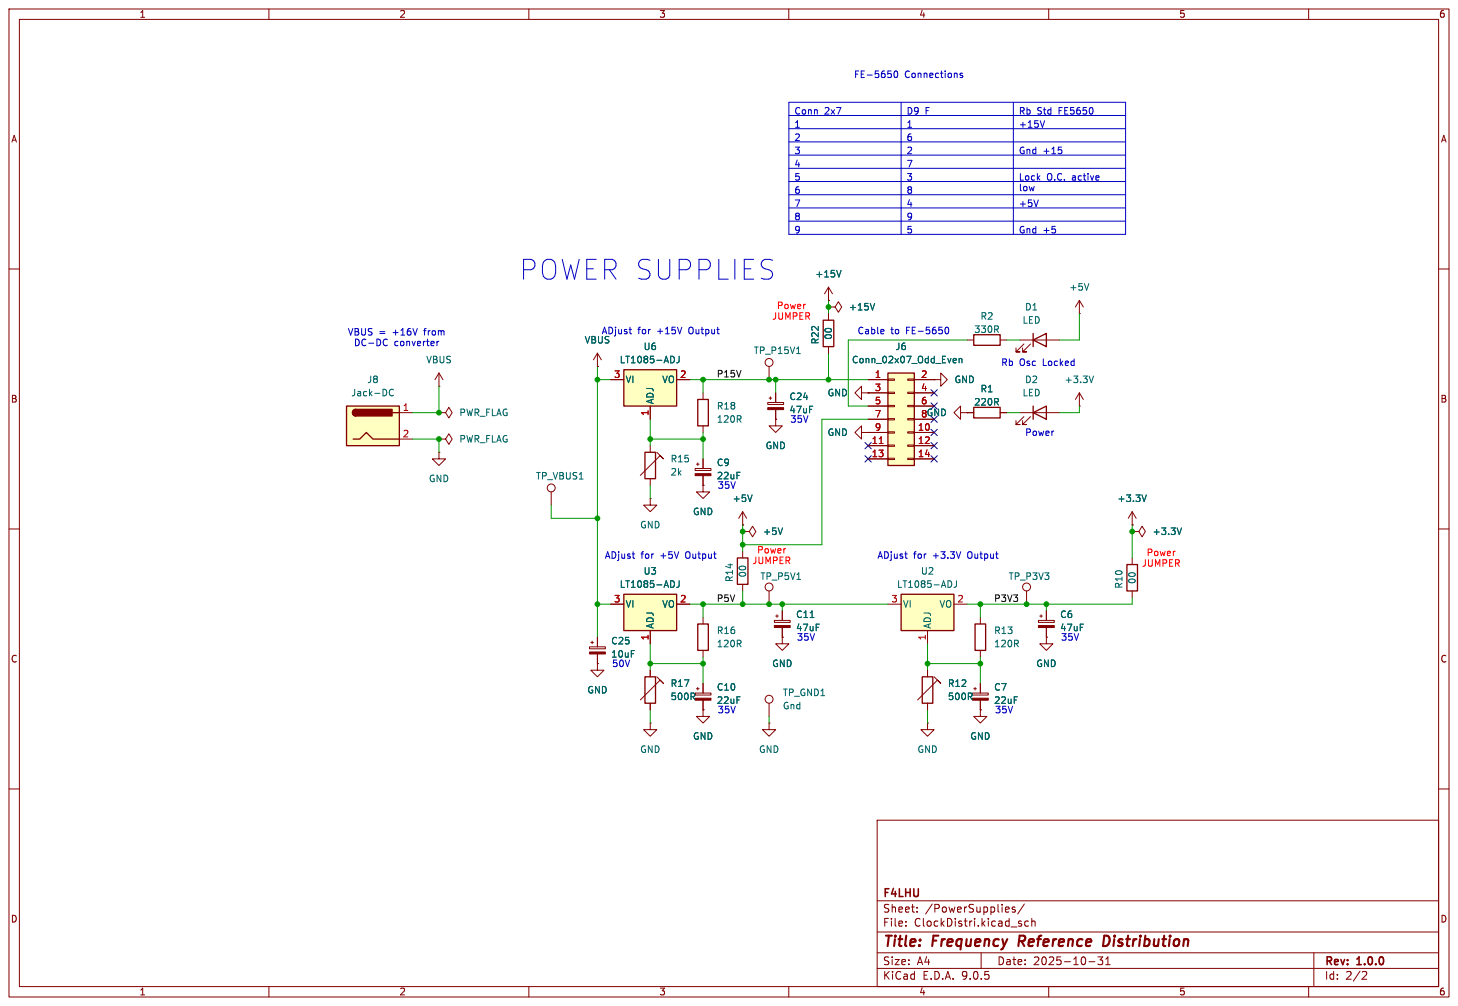
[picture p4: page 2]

File: ClockDistri.kicad_sch Sheet: /PowerSupplies/ F4LHU

Id: 2/2 Title: Frequency Reference Distribution

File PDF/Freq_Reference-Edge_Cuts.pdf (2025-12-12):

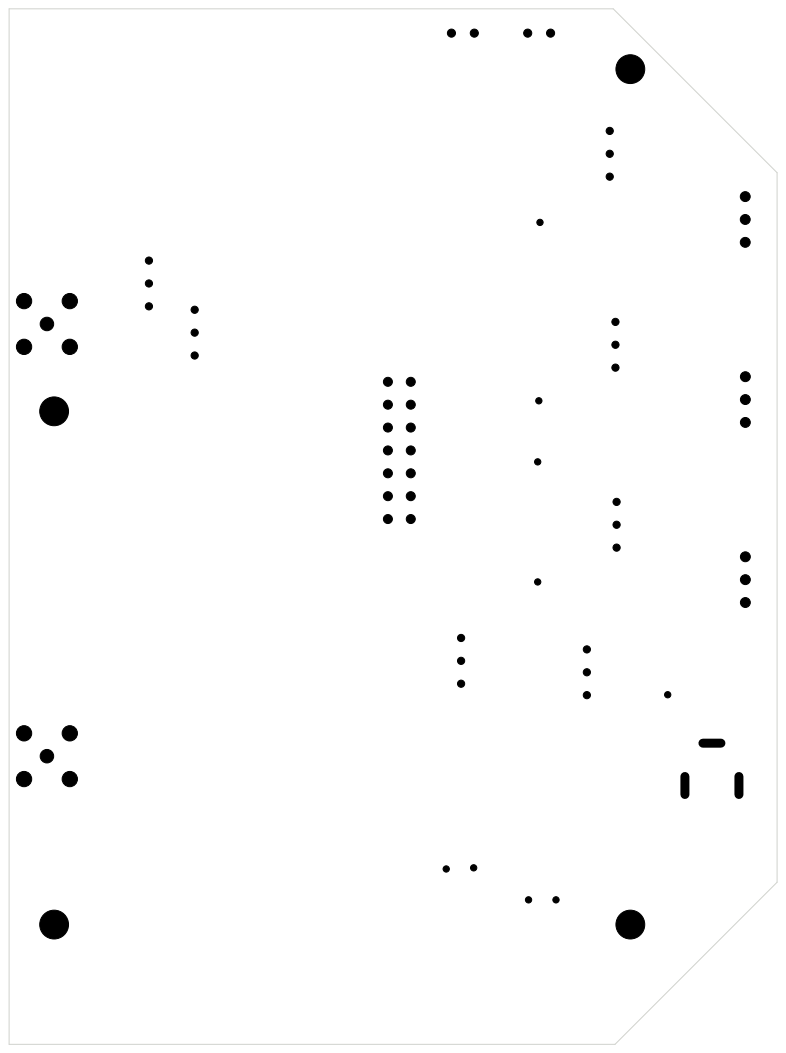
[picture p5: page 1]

Id: 1/2 Title: Frequency Reference Distribution

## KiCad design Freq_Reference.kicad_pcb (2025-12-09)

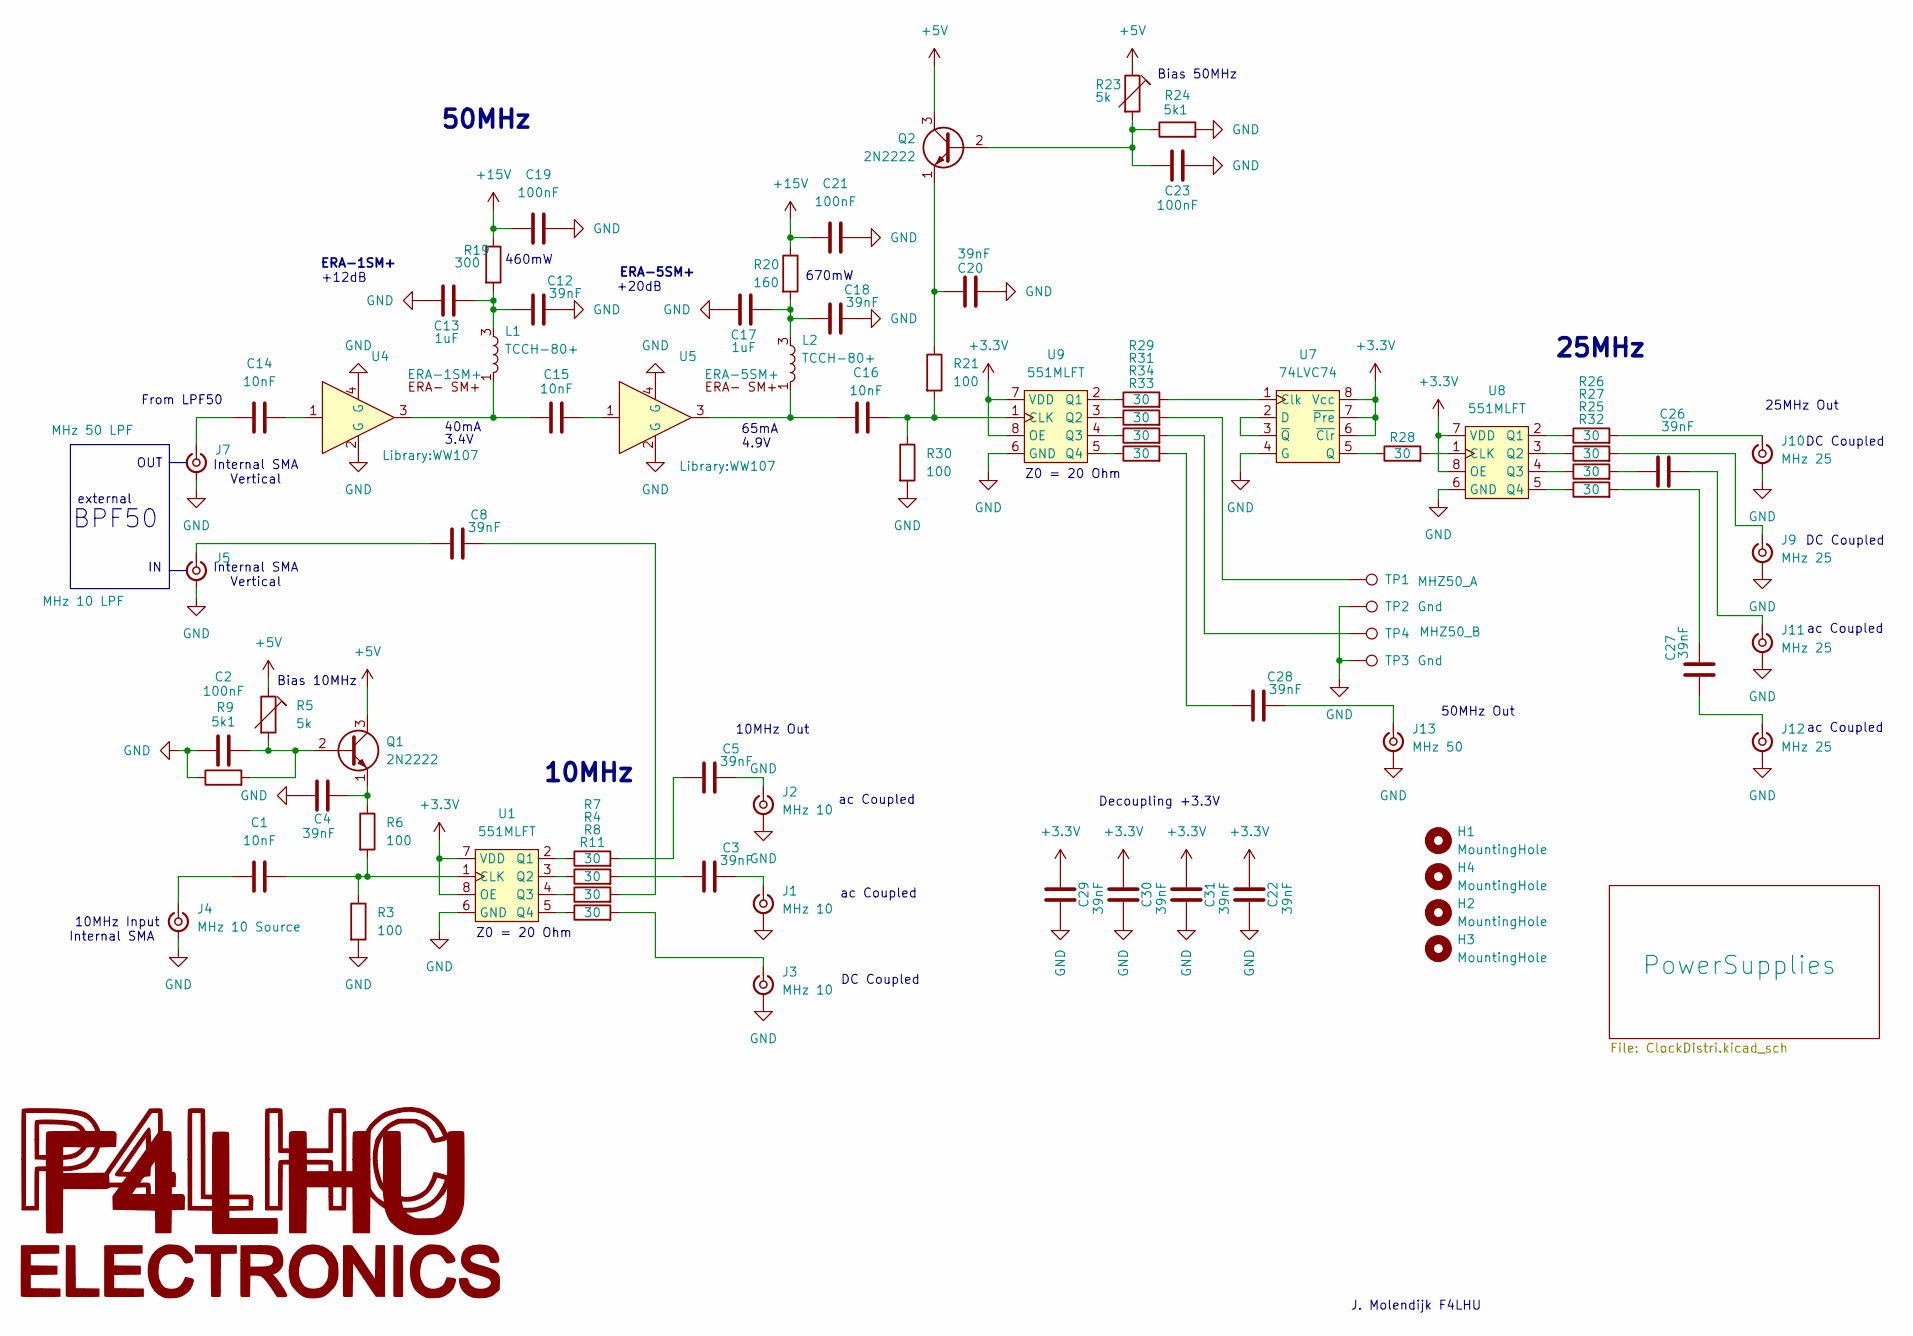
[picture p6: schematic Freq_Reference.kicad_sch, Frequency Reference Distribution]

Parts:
C1, C14, C15, C16: 10nF; C_1206_3216Metric_Pad1.33x1.80mm_HandSolder
C2, C19, C21, C23: 100nF; C_1206_3216Metric_Pad1.33x1.80mm_HandSolder
C3, C4, C5, C8, C12, C18, C20, C22, C26, C27, C28, C29, C30, C31: 39nF; C_1206_3216Metric_Pad1.33x1.80mm_HandSolder
C13, C17: 1uF; C_1206_3216Metric_Pad1.33x1.80mm_HandSolder
H1, H2, H3, H4: MountingHole; MountingHole_3.2mm_M3_ISO7380_Pad_TopBottom
J1, J2, J3: MHz 10; SMA_Amphenol_132289_EdgeMount
J4: MHz 10 Source; SMA_Amphenol_132289_EdgeMount
J5: MHz 10 LPF; SMA_Amphenol_132134-11_Vertical
J7: MHz 50 LPF; SMA_Amphenol_132134-11_Vertical
J9, J10, J11, J12: MHz 25; SMA_Amphenol_132289_EdgeMount
J13: MHz 50; SMA_Amphenol_132289_EdgeMount
L1, L2: TCCH-80+; Minicircuits_GU1604
Logo1: LOGO; F4LHU
Q1, Q2: 2N2222; TO-92_Inline_Wide
R3, R6, R21, R30: 100; R_1206_3216Metric_Pad1.30x1.75mm_HandSolder
R4, R7, R8, R11, R25, R26, R27, R28, R29, R31, R32, R33, R34: 30; R_1206_3216Metric_Pad1.30x1.75mm_HandSolder
R5, R23: 5k; Potentiometer_Bourns_3299W_Vertical
R9, R24: 5k1; R_1206_3216Metric_Pad1.30x1.75mm_HandSolder
R19: 300; R_2512_6332Metric_Pad1.40x3.35mm_HandSolder
R20: 160; R_2512_6332Metric_Pad1.40x3.35mm_HandSolder
TP1: MHZ50_A; TestPoint_THTPad_1.5x1.5mm_Drill0.7mm
TP2, TP3: Gnd; TestPoint_THTPad_1.5x1.5mm_Drill0.7mm
TP4: MHZ50_B; TestPoint_THTPad_1.5x1.5mm_Drill0.7mm
U1, U8, U9: 551MLFT; SOIC-8_5.3x6.2mm_P1.27mm
U4: ERA-1SM+; WW107
U5: ERA-5SM+; WW107
U7: 74LVC74; SSOP-8_2.95x2.8mm_P0.65mm

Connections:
+3.3V: C22.1, C29.1, C30.1, C31.1, U1.7 (VDD), U1.8 (OE), U7.6 (~Clr), U7.7 (~Pre), U7.8 (Vcc), U8.7 (VDD), U8.8 (OE), U9.7 (VDD), U9.8 (OE); also elsewhere on the board
+5V: Q1.3 (C), Q2.3 (C), R5.1, R23.1; also elsewhere on the board
+15V: C19.1, C21.1, R19.1, R20.1; also elsewhere on the board
GND: C2.1, C4.2, C12.2, C13.1, C17.1, C18.2, C19.2, C20.2, C21.2, C22.2, C23.2, C29.2, C30.2, C31.2, J1.2 (Ext), J2.2 (Ext), J3.2 (Ext), J4.2 (Ext), J5.2 (Ext), J7.2 (Ext), J9.2 (Ext), J10.2 (Ext), J11.2 (Ext), J12.2 (Ext), J13.2 (Ext), R3.2, R9.1, R24.2, R30.2, TP2.1, TP3.1, U1.6 (GND), U4.2 (G), U4.4 (G), U5.2 (G), U5.4 (G), U7.4 (G), U8.6 (GND), U9.6 (GND); also elsewhere on the board
unnamed: C3.1, R4.2
unnamed: C5.1, R7.2
unnamed: C8.2, R8.2
unnamed: C14.2, U4.1
unnamed: C15.2, U5.1
unnamed: C26.1, R25.2
unnamed: C27.2, R32.2
unnamed: C28.1, R33.2
unnamed: C3.2, J1.1 (In)
unnamed: C5.2, J2.1 (In)
unnamed: J3.1 (In), R11.2
unnamed: C1.1, J4.1 (In)
unnamed: C8.1, J5.1 (In)
unnamed: C14.1, J7.1 (In)
unnamed: J9.1 (In), R27.2
unnamed: J10.1 (In), R26.2
unnamed: C26.2, J11.1 (In)
unnamed: C27.1, J12.1 (In)
unnamed: C28.2, J13.1 (In)
unnamed: C12.1, C13.2, L1.3 (DC), R19.2
unnamed: C15.1, L1.1 (RF-DC), U4.3
unnamed: C17.2, C18.1, L2.3 (DC), R20.2
unnamed: C16.1, L2.1 (RF-DC), U5.3
unnamed: C2.2, Q1.2 (B), R5.2, R9.2
unnamed: C4.1, Q1.1 (E), R6.1
unnamed: C23.1, Q2.2 (B), R23.2, R24.1
unnamed: C20.1, Q2.1 (E), R21.1
unnamed: R31.2, TP1.1
unnamed: R34.2, TP4.1
unnamed: C1.2, R3.1, R6.2, U1.1 (CLK)
unnamed: R7.1, U1.2 (Q1)
unnamed: R4.1, U1.3 (Q2)
unnamed: R8.1, U1.4 (Q3)
unnamed: R11.1, U1.5 (Q4)
unnamed: R29.2, U7.1 (Clk)
unnamed: U7.2 (D), U7.3 (~Q)
unnamed: R28.1, U7.5 (Q)
unnamed: R28.2, U8.1 (CLK)
unnamed: R26.1, U8.2 (Q1)
unnamed: R27.1, U8.3 (Q2)
unnamed: R25.1, U8.4 (Q3)
unnamed: R32.1, U8.5 (Q4)
unnamed: C16.2, R21.2, R30.1, U9.1 (CLK)
unnamed: R29.1, U9.2 (Q1)
unnamed: R31.1, U9.3 (Q2)
unnamed: R34.1, U9.4 (Q3)
unnamed: R33.1, U9.5 (Q4)

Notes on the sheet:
Z0 = 20 Ohm
10MHz Input
Internal SMA
external
BPF50
670mW
10MHz Out
65mA
ac Coupled
40mA
ERA-1SM+
25MHz
DC Coupled
J. Molendijk F4LHU
Decoupling +3.3V
50MHz
From LPF50
3.4V
Internal SMA Vertical
10MHz
Bias 50MHz
+12dB
460mW
4.9V
OUT
Bias 10MHz
ERA-5SM+
25MHz Out
+20dB
50MHz Out

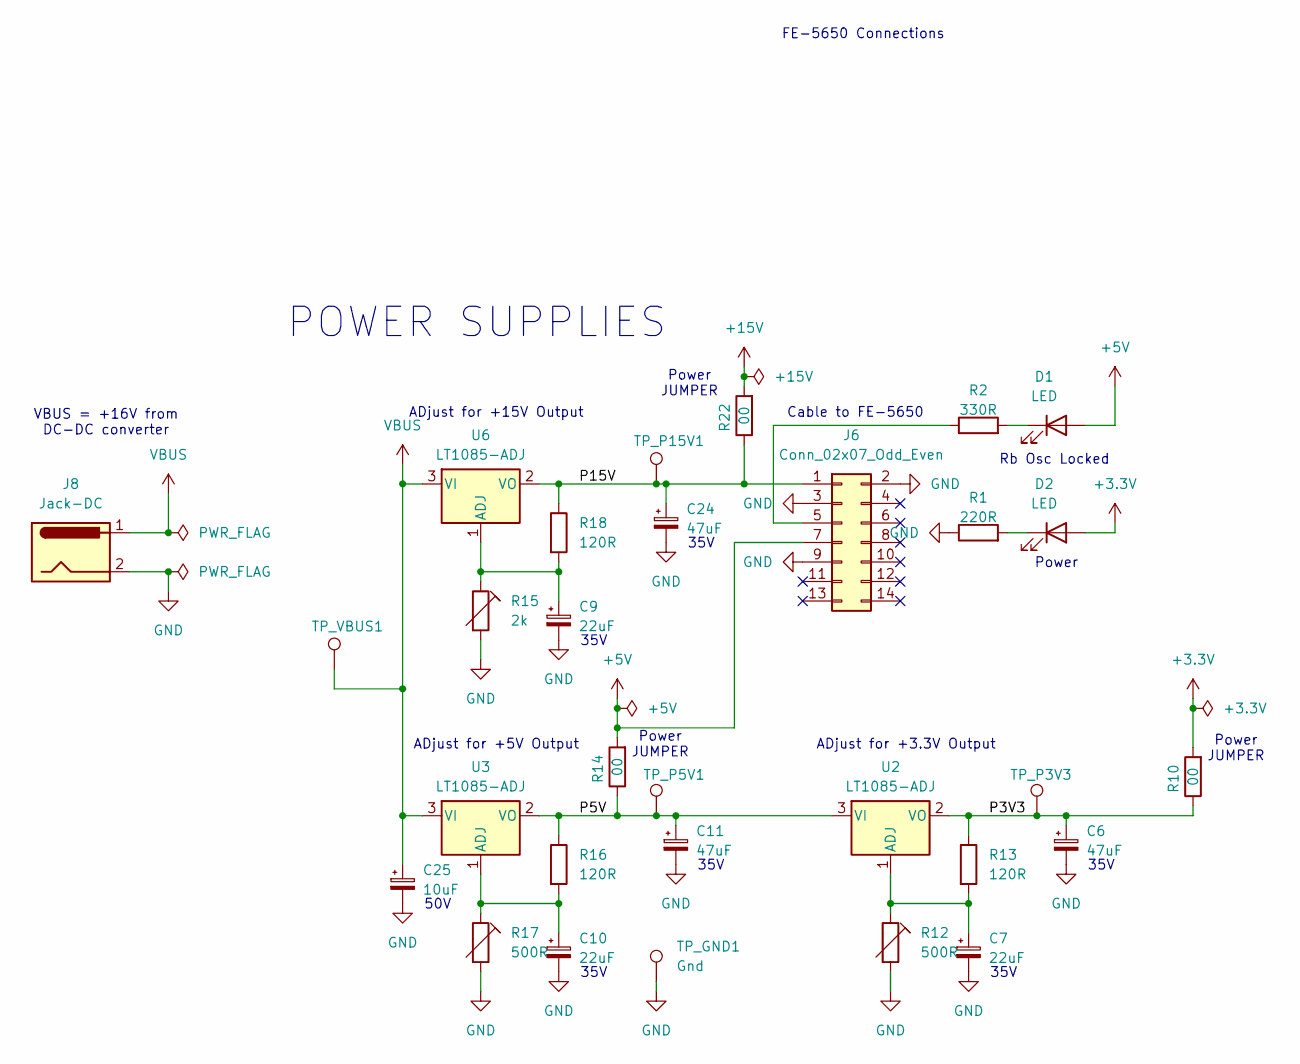
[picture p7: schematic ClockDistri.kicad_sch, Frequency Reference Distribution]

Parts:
C6, C11, C24: 47uF; CP_EIA-7343-31_Kemet-D_HandSolder
C7, C9, C10: 22uF; CP_EIA-7343-31_Kemet-D_HandSolder
C25: 10uF; CP_EIA-7343-31_Kemet-D_HandSolder
D1, D2: LED; LED_D3.0mm
J6: Conn_02x07_Odd_Even; PinHeader_2x07_P2.54mm_Vertical
J8: Jack-DC; BarrelJack_Horizontal
R1: 220R; R_1206_3216Metric_Pad1.30x1.75mm_HandSolder
R2: 330R; R_1206_3216Metric_Pad1.30x1.75mm_HandSolder
R10, R14, R22: 00; R_1206_3216Metric_Pad1.30x1.75mm_HandSolder
R12, R17: 500R; Potentiometer_Bourns_3299W_Vertical
R13, R16, R18: 120R; R_1206_3216Metric_Pad1.30x1.75mm_HandSolder
R15: 2k; Potentiometer_Bourns_3299W_Vertical
TP_GND1: Gnd; TestPoint_THTPad_1.5x1.5mm_Drill0.7mm
TP_P3V3: +3.3V; TestPoint_THTPad_1.5x1.5mm_Drill0.7mm
TP_P5V1: +5V; TestPoint_THTPad_1.5x1.5mm_Drill0.7mm
TP_P15V1: +15V; TestPoint_THTPad_1.5x1.5mm_Drill0.7mm
TP_VBUS1: +16V; TestPoint_THTPad_1.5x1.5mm_Drill0.7mm
U2, U3, U6: LT1085-ADJ; TO-220-3_Vertical

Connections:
+3.3V: D2.2 (A), R10.2; also elsewhere on the board
+5V: D1.2 (A), J6.7, R14.2; also elsewhere on the board
+15V: R22.2; also elsewhere on the board
/PowerSupplies/P3V3: C6.1, R10.1, R13.1, TP_P3V3.1, U2.2 (VO)
/PowerSupplies/P5V: C11.1, R14.1, R16.1, TP_P5V1.1, U2.3 (VI), U3.2 (VO)
/PowerSupplies/P15V: C24.1, J6.1, R18.1, R22.1, TP_P15V1.1, U6.2 (VO)
GND: C6.2, C7.2, C9.2, C10.2, C11.2, C24.2, C25.2, J6.2, J6.3, J6.9, J8.2, R1.1, R12.2, R15.2, R17.2, TP_GND1.1; also elsewhere on the board
unnamed: D1.1 (K), R2.2
unnamed: D2.1 (K), R1.2
unnamed: J6.5, R2.1
unnamed: C7.1, R12.1, R13.2, U2.1 (ADJ)
unnamed: C10.1, R16.2, R17.1, U3.1 (ADJ)
unnamed: C9.1, R15.1, R18.2, U6.1 (ADJ)
VBUS: C25.1, J8.1, TP_VBUS1.1, U3.3 (VI), U6.3 (VI)

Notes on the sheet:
35V
50V
Power JUMPER
Power
ADjust for +3.3V Output
POWER SUPPLIES
Cable to FE-5650
ADjust for +5V Output
VBUS = +16V from DC-DC converter
Rb Osc Locked
ADjust for +15V Output
FE-5650 Connections

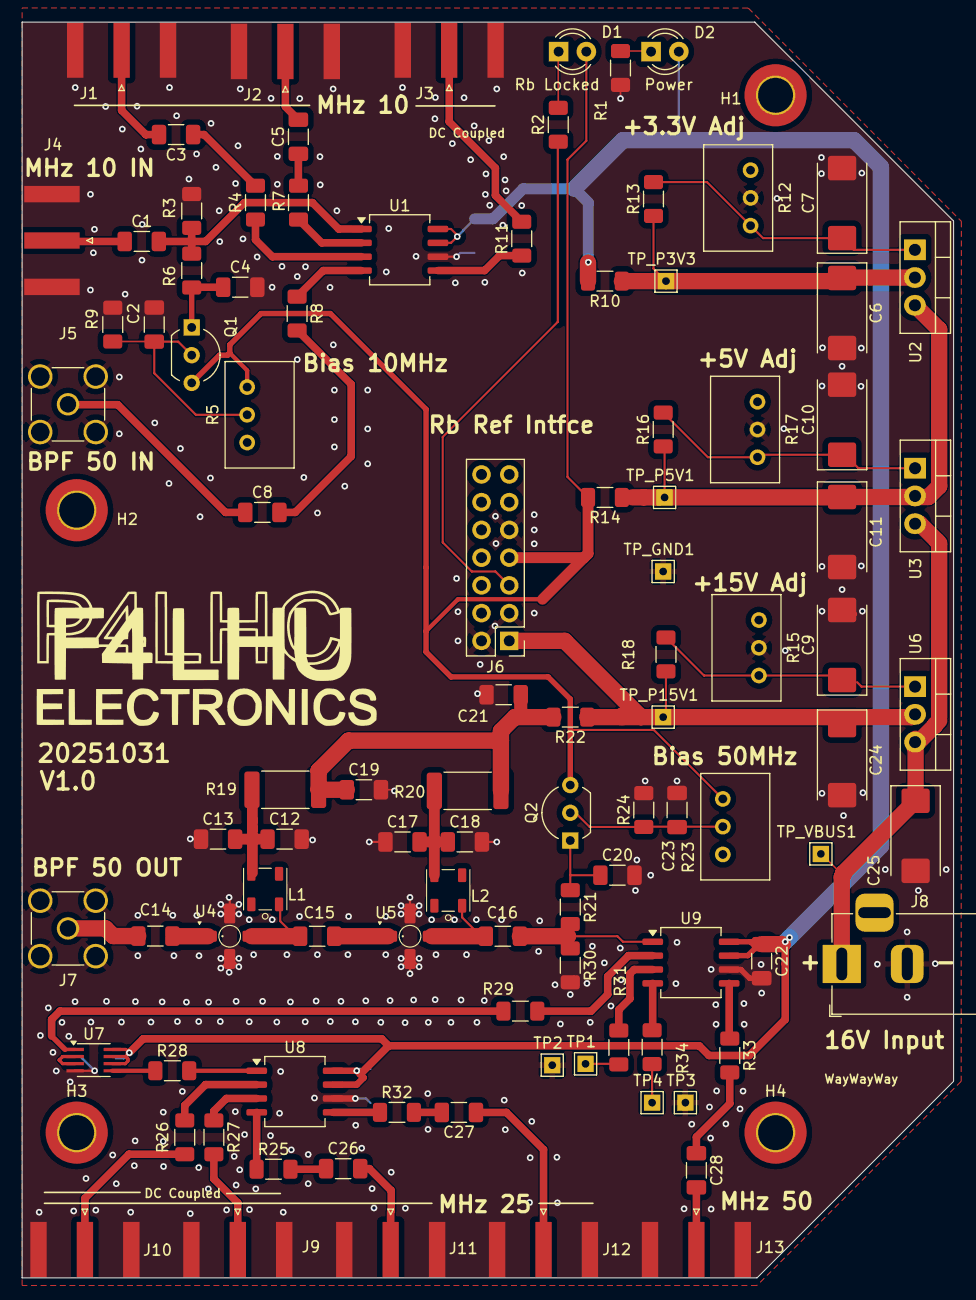
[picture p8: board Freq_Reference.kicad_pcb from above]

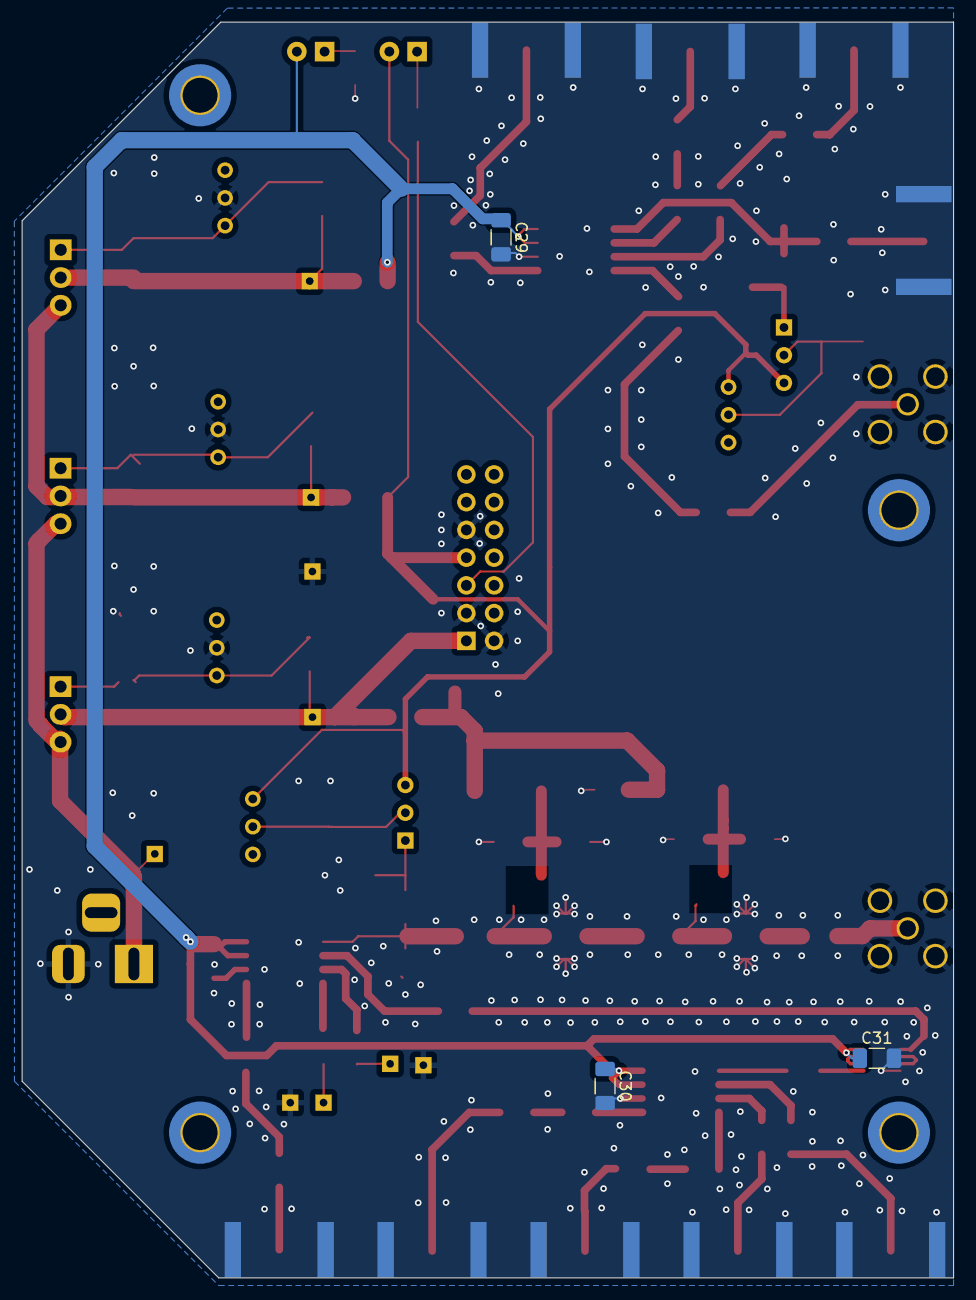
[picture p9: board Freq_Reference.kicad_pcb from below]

Board: 2 copper layers, 85.3 x 115.0 mm, 107 parts (3 on the bottom side), 61 nets.

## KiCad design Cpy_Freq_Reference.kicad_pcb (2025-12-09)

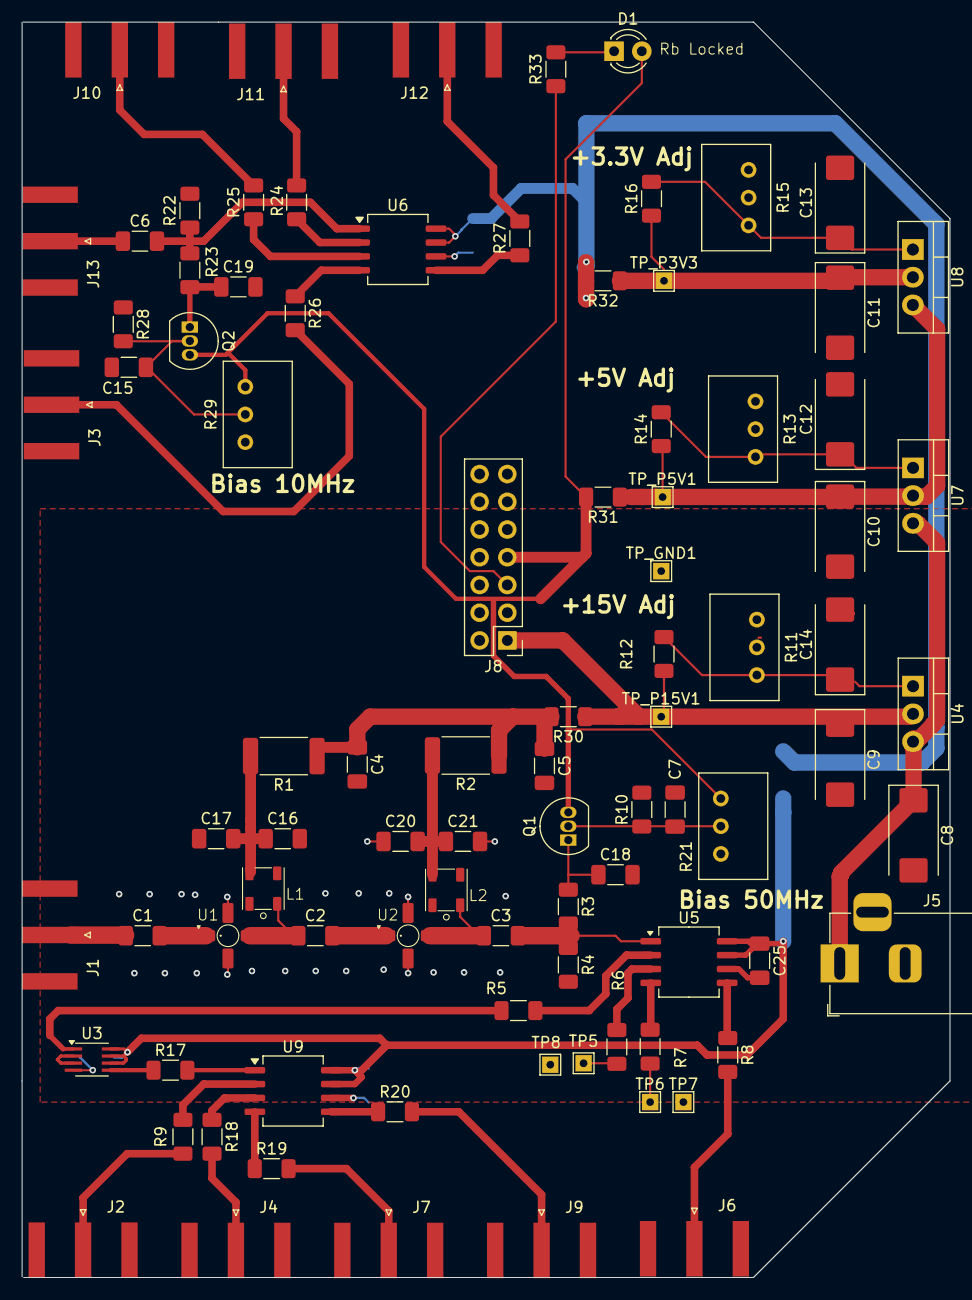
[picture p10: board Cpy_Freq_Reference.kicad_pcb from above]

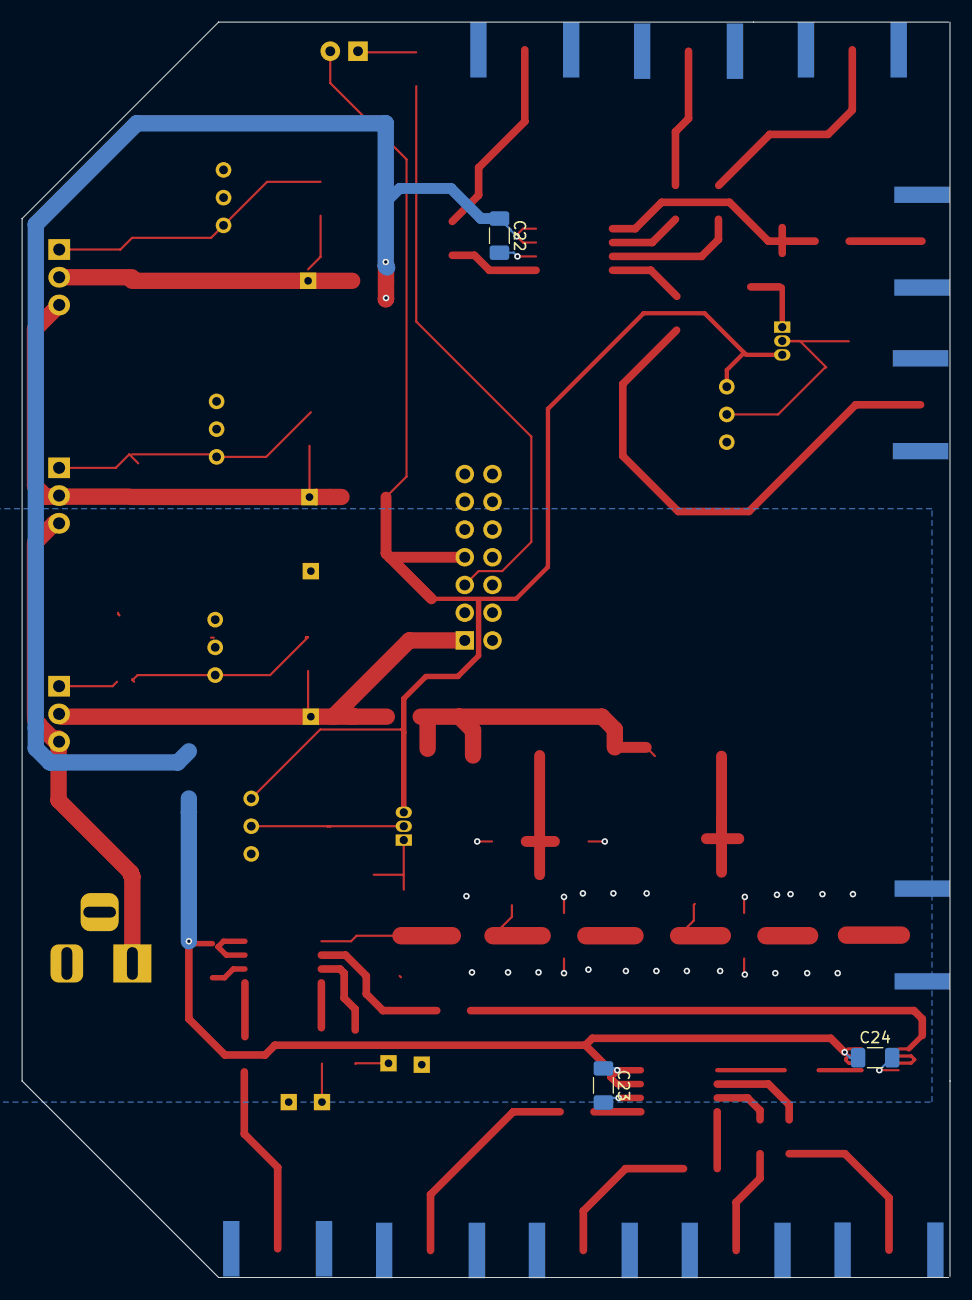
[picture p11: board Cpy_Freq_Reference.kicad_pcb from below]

Board: 2 copper layers, 85.0 x 115.0 mm, 93 parts (3 on the bottom side), 54 nets.

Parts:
C1, C2, C3, C6: 10nF; C_1206_3216Metric_Pad1.33x1.80mm_HandSolder
C4, C5, C7, C15: 100nF; C_1206_3216Metric_Pad1.33x1.80mm_HandSolder
C8: 10uF; CP_EIA-7343-31_Kemet-D_HandSolder
C9, C10, C11: 47uF; CP_EIA-7343-31_Kemet-D_HandSolder
C12, C13, C14: 22uF; CP_EIA-7343-31_Kemet-D_HandSolder
C16, C18, C19, C21, C22, C23, C24, C25: 39nF; C_1206_3216Metric_Pad1.33x1.80mm_HandSolder
C17, C20: 1uF; C_1206_3216Metric_Pad1.33x1.80mm_HandSolder
D1: LED; LED_D3.0mm
J1: MHz 50 LPF; SMA_Amphenol_132289_EdgeMount
J2, J4, J7, J9: MHz 25; SMA_Amphenol_132289_EdgeMount
J3: MHz 10 LPF; SMA_Amphenol_132289_EdgeMount
J5: Jack-DC; BarrelJack_Horizontal
J6: MHz 50; SMA_Amphenol_132289_EdgeMount
J8: Conn_02x07_Odd_Even; PinHeader_2x07_P2.54mm_Vertical
J10, J11, J12: MHz 10; SMA_Amphenol_132289_EdgeMount
J13: MHz 10 Source; SMA_Amphenol_132289_EdgeMount
L1, L2: TCCH-80+; Minicircuits_GU1604
Q1, Q2: 2N2222; TO-92_Inline
R1: 300; R_2512_6332Metric_Pad1.40x3.35mm_HandSolder
R2: 160; R_2512_6332Metric_Pad1.40x3.35mm_HandSolder
R3, R4, R22, R23: 100; R_1206_3216Metric_Pad1.30x1.75mm_HandSolder
R5, R6, R7, R8, R9, R17, R18, R19, R20, R24, R25, R26, R27: 30; R_1206_3216Metric_Pad1.30x1.75mm_HandSolder
R10, R28: 5k1; R_1206_3216Metric_Pad1.30x1.75mm_HandSolder
R11: 2k; Potentiometer_Bourns_3299W_Vertical
R12, R14, R16: 120R; R_1206_3216Metric_Pad1.30x1.75mm_HandSolder
R13, R15: 500R; Potentiometer_Bourns_3299W_Vertical
R21, R29: 5k; Potentiometer_Bourns_3299W_Vertical
R30, R31, R32: 00; R_1206_3216Metric_Pad1.30x1.75mm_HandSolder
R33: 330R; R_1206_3216Metric_Pad1.30x1.75mm_HandSolder
TP5: MHZ50_A; TestPoint_THTPad_1.5x1.5mm_Drill0.7mm
TP6: MHZ50_B; TestPoint_THTPad_1.5x1.5mm_Drill0.7mm
TP7, TP8: Gnd; TestPoint_THTPad_1.5x1.5mm_Drill0.7mm
TP_GND1: Gnd; TestPoint_THTPad_1.5x1.5mm_Drill0.7mm
TP_P3V3: +3.3V; TestPoint_THTPad_1.5x1.5mm_Drill0.7mm
TP_P5V1: +5V; TestPoint_THTPad_1.5x1.5mm_Drill0.7mm
TP_P15V1: +15V; TestPoint_THTPad_1.5x1.5mm_Drill0.7mm
U1: 1; WW107
U2: 5; WW107
U3: 74LVC74; SSOP-8_2.95x2.8mm_P0.65mm
U4, U7, U8: LT1085-ADJ; TO-220-3_Vertical
U5, U6, U9: 551MLFT; SOIC-8_5.3x6.2mm_P1.27mm

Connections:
+3.3V: C22.1, C23.1, C24.1, C25.1, R32.2, U3.6 (~Clr), U3.7 (~Pre), U3.8 (Vcc), U5.7 (VDD), U5.8 (OE), U6.7 (VDD), U6.8 (OE), U9.7 (VDD), U9.8 (OE)
+5V: D1.2 (A), J8.7, Q1.3 (C), Q2.3 (C), R21.1, R29.1, R31.2
+15V: C4.1, C5.1, R1.1, R2.1, R30.2
/PowerSupplies/P3V3: C11.1, R16.1, R32.1, TP_P3V3.1, U8.2 (VO)
/PowerSupplies/P5V: C10.1, R14.1, R31.1, TP_P5V1.1, U7.2 (VO), U8.3 (VI)
/PowerSupplies/P15V: C9.1, J8.1, R12.1, R30.1, TP_P15V1.1, U4.2 (VO)
GND: C4.2, C5.2, C7.2, C8.2, C9.2, C10.2, C11.2, C12.2, C13.2, C14.2, C15.1, C16.2, C17.1, C18.2, C19.2, C20.1, C21.2, C22.2, C23.2, C24.2, C25.2, J1.2 (Ext), J2.2 (Ext), J3.2 (Ext), J4.2 (Ext), J5.2, J6.2 (Ext), J7.2 (Ext), J8.2, J8.3, J8.9, J9.2 (Ext), J10.2 (Ext), J11.2 (Ext), J12.2 (Ext), J13.2 (Ext), R4.2, R10.2, R11.2, R13.2, R15.2, R22.2, R28.1, TP7.1, TP8.1, TP_GND1.1, U1.2 (G), U1.4 (G), U2.2 (G), U2.4 (G), U3.4 (G), U5.6 (GND), U6.6 (GND), U9.6 (GND)
unnamed: C1.2, U1.1
unnamed: C2.2, U2.1
unnamed: D1.1 (K), R33.2
unnamed: C1.1, J1.1 (In)
unnamed: J2.1 (In), R9.2
unnamed: J3.1 (In), R26.2
unnamed: J4.1 (In), R18.2
unnamed: J6.1 (In), R8.2
unnamed: J7.1 (In), R19.2
unnamed: J8.5, R33.1
unnamed: J9.1 (In), R20.2
unnamed: J10.1 (In), R25.2
unnamed: J11.1 (In), R24.2
unnamed: J12.1 (In), R27.2
unnamed: C6.1, J13.1 (In)
unnamed: C16.1, C17.2, L1.3 (DC), R1.2
unnamed: C2.1, L1.1 (RF-DC), U1.3
unnamed: C20.2, C21.1, L2.3 (DC), R2.2
unnamed: C3.1, L2.1 (RF-DC), U2.3
unnamed: C7.1, Q1.2 (B), R10.1, R21.2
unnamed: C18.1, Q1.1 (E), R3.1
unnamed: C15.2, Q2.2 (B), R28.2, R29.2
unnamed: C19.1, Q2.1 (E), R23.1
unnamed: R6.2, TP5.1
unnamed: R7.2, TP6.1
unnamed: R5.2, U3.1 (Clk)
unnamed: U3.2 (D), U3.3 (~Q)
unnamed: R17.1, U3.5 (Q)
unnamed: C14.1, R11.1, R12.2, U4.1 (ADJ)
unnamed: C3.2, R3.2, R4.1, U5.1 (CLK)
unnamed: R5.1, U5.2 (Q1)
unnamed: R6.1, U5.3 (Q2)
unnamed: R7.1, U5.4 (Q3)
unnamed: R8.1, U5.5 (Q4)
unnamed: C6.2, R22.1, R23.2, U6.1 (CLK)
unnamed: R24.1, U6.2 (Q1)
unnamed: R25.1, U6.3 (Q2)
unnamed: R26.1, U6.4 (Q3)
unnamed: R27.1, U6.5 (Q4)
unnamed: C12.1, R13.1, R14.2, U7.1 (ADJ)
unnamed: C13.1, R15.1, R16.2, U8.1 (ADJ)
unnamed: R17.2, U9.1 (CLK)
unnamed: R9.1, U9.2 (Q1)
unnamed: R18.1, U9.3 (Q2)
unnamed: R19.1, U9.4 (Q3)
unnamed: R20.1, U9.5 (Q4)
VBUS: C8.1, J5.1, U4.3 (VI), U7.3 (VI)

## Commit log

2025-12-09 Updated with KiCad gitignore suggestions from GitHub
2025-12-10 Added Mounting Sequence and Commissioning to README.md
2025-12-10 Added LEDs and some corrections
2025-12-13 removed file ClockDistri.kicad.sch from project folder
    [ClockDistri.kicad_sch]
2025-12-13 Restored file ClockDistri.kicad.sch containing powering page
2026-02-02 Now added contents of ClockDistrti.kicad_sch
    [ClockDistri.kicad_sch]
